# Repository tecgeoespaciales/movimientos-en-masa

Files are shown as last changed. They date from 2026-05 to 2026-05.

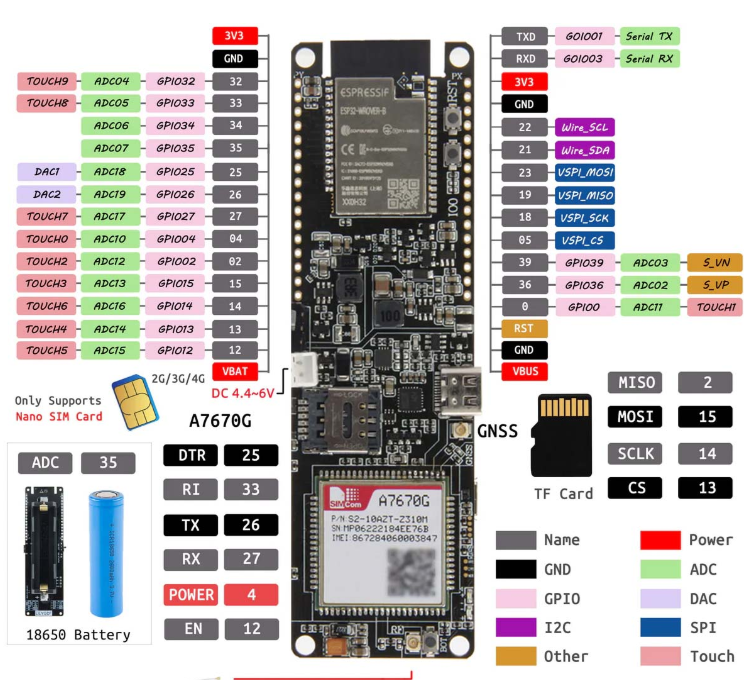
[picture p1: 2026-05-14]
docs-movimientos-en-masa/PINOUT-A7670G/PINOUT ESP32-A7670G.png

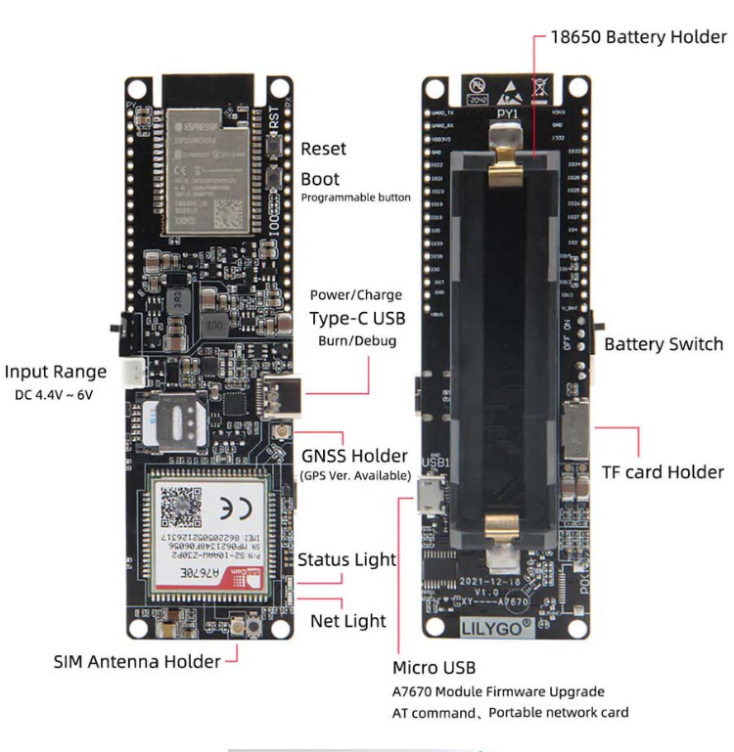
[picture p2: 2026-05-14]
docs-movimientos-en-masa/PINOUT-A7670G/ESP32-A7670G.png

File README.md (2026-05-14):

# Estación de monitoreo automática (EMA) - Movimientos en masa 🛰️⛰️

> Espacio de trabajo para la rama **profesional** del dispositivo **movimientos-en-masa**, desarrollado bajo los estándares técnicos del **Servicio Geológico Colombiano (SGC)**.

## 📂 Módulos del proyecto
Para una navegación detallada por los componentes del sistema, acceda a los siguientes módulos:

* 📑 **[docs-movimientos-en-masa](./Docs/)** – Manuales técnicos, de operación y seguridad.
* 🔌 **[hardware-movimientos-en-masa](./Hardware/)** – Esquemas electrónicos, PinOut y listado de componentes.
* 💻 **[firmware-movimientos-en-masa](./Firmware_ESP32/)** – Código fuente para ESP32 con protocolos de comunicación segura.
* ⚙️ **[mechanical-movimientos-en-masa](./Mechanical/)** – Archivos STL para impresión 3D en resina y ABS.
* 🎬 **[video-tutoriales-movimientos-en-masa](./Videos/)** – Guías visuales paso a paso para la operación y extracción de datos en campo.

---

## 📝 Descripción general
La **EMA (Estación de Monitoreo Automática)** es un sistema IoT de alta precisión diseñado para la detección temprana de deslizamientos. Utiliza un sensor óptico acoplado a un mecanismo de carrete y nylon para medir desplazamientos del terreno, transmitiendo datos en tiempo real mediante tecnología LTE.

## 🛠️ Especificaciones técnicas
* **Microcontrolador:** ESP32-WROVER-B (LilyGO T-A7670G).
* **Comunicación:** Módem SIMCom A7670G (Protocolo MQTT).
* **Sensor:** Encoder de herradura infrarrojo H206 (125 pulsos por metro).
* **Estampa:** RTC DS3231 para estampado de tiempo preciso.
* **Energía:** Panel solar 15W + batería Litio 18650.
* **Materiales:** Carrete y guías impresos en **resina ABS** de alta resistencia.

## 📐 Metodología de medición
La distancia de desplazamiento ($D$) se obtiene mediante el conteo de pulsos ($P$):
$$D = P \times 0.8000 \, \text{cm}$$

---

## 🔐 Seguridad y telemetría
El sistema garantiza la integridad de los datos para el SGC mediante:
1. **Capa de transporte:** Conexión cifrada **TLS (Puerto 1883)** hacia MQTT.

---

## 🚀 Guía de operación paso a paso

### 1. Preparación
* Instalar **Nano SIM** (Claro u operador de preferencia) y **MicroSD** (FAT32).
* Cargar batería 18650 (voltaje > 3.7V).

### 2. Calibración e instalación
* Fijar la caja hermética 15x15 en el sitio de monitoreo.
* Enrollar el nylon en el carrete y alinearlo con el sensor H206.
* Anclar el extremo del nylon al punto de referencia en el terreno.

### 3. Puesta en marcha
* Encender el interruptor. El sistema iniciará automáticamente el registro en red y la conexión MQTT.
* Verificar en el Dashboard (Node-RED) la recepción del primer paquete.

### 4. Descarga de datos (Modo local)
* En zonas sin cobertura, conectarse al Wi-Fi `EMA_SGC_CONFIG`.
* Acceder a `192.168.4.1` desde un navegador para descargar el archivo `LOGS.CSV`.

---

## ⚠️ Mantenimiento
* Limpiar el panel solar cada 3 meses, o antes de ser necesario.
* Revisar la tensión del nylon trenzado cada 3 meses , o antes de ser necesario.

---
**Autor:** Jhoiner Andretty Silva Montaño  
**Entidad:** Servicio Geológico Colombiano  
**Año:** 2026

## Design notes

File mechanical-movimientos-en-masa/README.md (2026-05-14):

# ⚙️ Especificaciones de fabricación mecánica (híbrido ABS - resina)

Este directorio contiene los archivos de diseño industrial para el ensamble del nodo de monitoreo **EMA - Movimientos en masa**. El sistema utiliza una combinación estratégica de materiales para garantizar precisión milimétrica y durabilidad estructural en campo.

## 📂 Inventario de piezas (.STL)

1.  **`CARRETE-CALIBRADOR.stl`**: Componente principal de medición. Su diámetro de 5.10 cm está optimizado para una resolución de 0.801 cm por pulso.
    * *Relación de campo:* 125 pulsos equivalen a 100 cm de desplazamiento lineal.
2.  **`ENCODER-8MM.stl`**: Acople de precisión diseñado para vincular el eje del encoder de 8mm con el sistema de rotación sin juegos mecánicos.
3.  **`CARRETE-NYLON.stl`**: Carrete de alta resistencia para el almacenamiento del hilo trenzado de 8 hilos.
4.  **`SOPORTE-H206.stl`**: Estructura de anclaje que garantiza el alineamiento perfecto entre el sensor óptico y el disco encoder.

## 🛠 Estándar de manufactura

Para asegurar el correcto funcionamiento del nodo bajo condiciones ambientales reales, se establecen los siguientes parámetros:

### 1. Componentes estructurales (ABS - FDM)
* **Material:** ABS (acrilonitrilo butadieno estireno).
* **Piezas:** Chasis, soportes y carrete de nylon.
* **Configuración:** Relleno al 60% (Giroide) y mínimo 4 capas de pared.
* **Propiedades:** Alta resistencia al impacto y estabilidad térmica hasta 60°C.

### 2. Componentes de Precisión (resina ABS - SLA/DLP)
* **Material:** Resina de ingeniería (Tough o ABS).
* **Piezas:** `CARRETE-CALIBRADOR` y `ENCODER-8MM`.
* **Propiedades:** Acabado superficial liso que minimiza la fricción y garantiza la fidelidad del conteo.

## 🔧 Notas de Ensamble y Mantenimiento

* **Alineación:** El sensor H206 debe estar centrado con las ranuras del disco para evitar errores de lectura por vibración o desajuste.
* **Fijación:** Se requiere tornillería M3 para el aseguramiento de los componentes al chasis.
* **Limpieza:** Mantener el disco encoder libre de polvo. Utilizar alcohol isopropílico únicamente para la limpieza del sensor óptico.

---
*Diseño y desarrollo técnico por: **Jhoiner Andretty Silva Montaño***

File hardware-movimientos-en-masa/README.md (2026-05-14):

# hardware-movimientos-en-masa
# 🔌 Hardware y electrónica - Nodo EMA

Este directorio contiene la especificación técnica de los componentes físicos y el esquema de conexiones desarrollado para el **Servicio Geológico Colombiano**. El diseño está optimizado para la detección de movimientos en masa mediante un sistema híbrido de alta precisión y bajo consumo.

## 📍 Análisis de componentes y conexiones (PinOut)

Cada terminal y periférico visualizado en el esquema de conexiones cumple una función vital para la autonomía y precisión del nodo:

### 1. Sensor óptico de herradura H206
* **Ubicación:** Conectado al **GPIO 32**.
* **Función:** Es el sensor principal de medición. Detecta la interrupción del haz infrarrojo al paso de las ranuras del disco encoder.
* **Detalle Técnico:** Configurado con una resistencia de **Pull-Up de 100kΩ** para estabilizar la señal y minimizar el consumo en *Deep Sleep*.

### 2. Unidad de procesamiento (LilyGO T-A7670G)
* **ESP32-WROVER-E:** Gestiona la lógica de control, el almacenamiento y la pila de protocolos.
* **Módem A7670G (Pines IO26/IO27):** Interfaz UART para el envío de telemetría GPRS/MQTT hacia el servidor central.
* **Control de Encendido (IO12/IO4):** Pines dedicados a la gestión de energía del módem, permitiendo apagarlo completamente cuando no hay transmisión.

### 3. Sincronización y tiempo (DS3231)
* **Interfaz:** Bus I2C (**SDA: IO21 / SCL: IO22**).
* **Función:** Garantiza que cada registro tenga un *timestamp* exacto, permitiendo la reconstrucción cronológica de los eventos geológicos.

### 4. Gestión energética solar
* **Panel solar:** 15W Modelo CL1615.
* **Lectura de Batería (IO35):** Entrada analógica (ADC) que permite al firmware monitorear el nivel de carga y reportarlo en la trama de datos para mantenimiento preventivo.

### 5. Almacenamiento redundante (MicroSD)
* **Interfaz:** Bus SPI (**CS: IO13**).
* **Función:** Respaldo físico de archivos CSV. Asegura que los datos no se pierdan si falla la cobertura celular.

## ⚙️ Especificaciones mecánicas integradas
Para asegurar la fidelidad del dato del sensor H206, el hardware se apoya en:
* **Eje:** Varilla lisa de acero de 8mm.
* **Soportes:** Rodamientos **KFL08** de alta eficiencia para un giro sin fricción.
* **Tracción:** Nylon trenzado de 8 hilos (elongación nula).

## 🛠️ Guía de ensamble y mantenimiento
1.  **Alineación crítica:** El disco encoder debe estar perfectamente centrado en la herradura del sensor H206 para evitar rozamientos.
2.  **Protección ambiental:** El hardware debe alojarse en la **Caja de paso 15x15 hermética** para proteger los circuitos de la humedad y el polvo.
3.  **Botón de servicio (IO0):** Se utiliza para activar el portal Wi-Fi local sin necesidad de abrir el equipo en campo.

---
**Autor:** Jhoiner Andretty Silva Montaño  
**Entidad:** Servicio Geológico Colombiano  
**Año:** 2026

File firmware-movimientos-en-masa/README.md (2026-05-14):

# 💾 Firmware EMA - Sistema de monitoreo de movimientos en masa

Este directorio contiene el desarrollo lógico integral para el microcontrolador **ESP32 (LilyGO T-A7670G)**. El firmware ha sido diseñado para garantizar la captura precisa de desplazamientos superficiales y su transmisión telemática bajo condiciones ambientales críticas.

## ❓ ¿Para qué sirve esta carpeta?
Esta carpeta es el **núcleo del sistema**. El firmware aquí alojado actúa como el "cerebro" del nodo EMA, encargándose de:
* **Interpretar el movimiento:** Traduce las señales físicas del sensor H206 en datos métricos de desplazamiento.
* **Gestión inteligente:** Controla cuándo el equipo debe "dormir" para ahorrar batería y cuándo debe "despertar" para reportar una alerta.
* **Puente de comunicación:** Transforma los datos recolectados en tramas MQTT para enviarlas vía satelital/celular al centro de datos del SGC.
* **Seguridad de datos:** Administra el respaldo local (MicroSD/LittleFS) para que nunca se pierda información por falta de señal.

## 🏗️ Arquitectura del software (FreeRTOS)
Para garantizar que no se pierda ningún pulso del encoder durante las tareas de comunicación, el firmware utiliza una arquitectura de doble núcleo:
* **Core 1 (Prioridad Crítica):** Ejecuta la tarea de vigilancia del sensor óptico H206. Detecta flancos de subida y bajada en el Pin 32 en tiempo real.
* **Core 0 (Gestión de Red):** Administra la pila TCP/IP, los comandos AT del módem A7670G y la sesión MQTT.

## ⚡ Gestión de energía y eficiencia
El sistema está optimizado para funcionar con un panel solar de 15W y una batería de respaldo:
* **Modo Deep Sleep:** El ESP32 entra en sueño profundo, reduciendo el consumo a microamperios.
* **Wake-up (EXT0):** El sistema despierta instantáneamente ante cualquier rotación del disco encoder.
* **Wake-up (Timer):** Reporte de estado de batería y señal cada hora.
* **Hardware:** Se implementa una resistencia de pull-up de 100kΩ para minimizar fugas de corriente en reposo.

## 🔐 Configuración de seguridad (Paso a Paso)
El firmware utiliza el archivo `config_env.h` para gestionar credenciales sensibles sin exponerlas en el historial de Git. Siga estas instrucciones para compilar:

1. En esta carpeta, cree un archivo nuevo llamado exactamente `config_env.h`.
2. Copie y pegue la siguiente estructura:

```cpp
#ifndef CONFIG_ENV_H
#define CONFIG_ENV_H

// --- CREDENCIALES GPRS (APN) ---
#define SECRET_APN        "internet.comcel.com.co" 
#define SECRET_GPRS_USER  ""
#define SECRET_GPRS_PASS  ""

// --- CONFIGURACIÓN BROKER MQTT ---
#define SECRET_MQTT_SERVER "00.000.000.0"   // IP Servidor a usar
#define SECRET_MQTT_PORT   1883
#define SECRET_MQTT_USER   "tu_usuario"
#define SECRET_MQTT_PASS   "tu_clave"
#define SECRET_MQTT_TOPIC  "movimientos_masa/final"

// --- ACCESO TÉCNICO LOCAL ---
#define SECRET_WIFI_AP_PASS "12345678" 

#endif

//-- AUTOR --
//**Autor:** Jhoiner Andretty Silva Montaño  
//**Entidad:** Servicio Geológico Colombiano  
//**Año:** 2026

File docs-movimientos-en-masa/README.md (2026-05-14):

# 📚 Documentación técnica y manuales - nodo EMA

Este directorio centraliza la base de conocimiento del sistema de monitoreo de movimientos en masa. Aquí se encuentran los manuales de operación, las guías de referencia y los registros de control desarrollados para asegurar la correcta implementación y mantenimiento del nodo en campo.

## 📄 Recursos disponibles en esta carpeta

### 1. Manual de operación principal
* **Archivo:** `Manual_operacion_EMA.docx` (Anteriormente *PlantillaManualdeoperacin_1.docx*)
* **Contenido:** Guía exhaustiva que cubre desde los objetivos del proyecto hasta los protocolos de instalación. Es el documento maestro para entender el funcionamiento del hardware y software.

### 2. Guía de calibración y resolución
De acuerdo con las pruebas de ingeniería documentadas, el sistema utiliza los siguientes parámetros para la conversión de datos mecánicos a digitales:
* **Resolución:** 0.801 cm por cada pulso del sensor H206.
* **Equivalencia:** 125 pulsos corresponden a 100 cm (1 metro) de desplazamiento.
* **Componente crítico:** Carrete calibrador de 5.10 cm de diámetro.

### 3. Control de versiones y cambios
* **Archivo:** `Control_de_Cambios.png` (Referencia visual)
* **Uso:** Registro histórico de las actualizaciones realizadas en el firmware, mejoras en el diseño de las piezas 3D y ajustes en los protocolos de comunicación MQTT.

## 🛠️ Referencias técnicas complementarias
Para profundizar en los submódulos del nodo, se recomienda consultar las siguientes referencias mencionadas en el manual:
* **Hardware:** LilyGO T-A7670 Series hardware manual.
* **Comandos AT:** SIMCom A7670 Series command manual (Envío de tramas CSV).
* **Sensor:** Datasheet genérico H206.

## 📊 Gestión y visualización
La documentación describe el flujo de datos hacia la interfaz de **Node-RED**, detallando la configuración de los dashboards para la visualización de desplazamientos y niveles de batería reportados por el nodo.

---
**Autor:** Jhoiner Andretty Silva Montaño  
**Entidad:** Servicio Geológico Colombiano  
**Año:** 2026

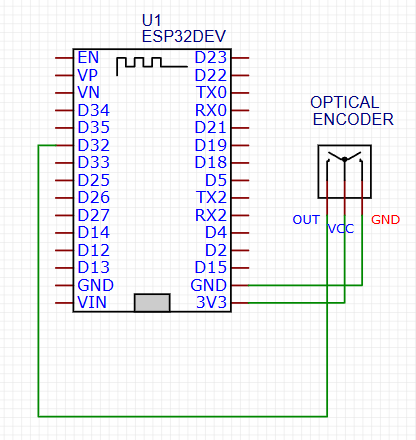
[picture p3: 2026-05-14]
docs-movimientos-en-masa/ESQUEMATICOS-MOV-MASA/CIRCUITO_ESP32-SENSOR_H206.png

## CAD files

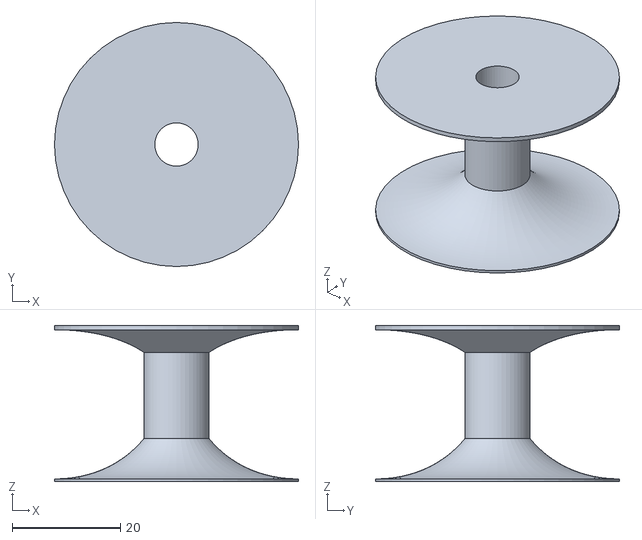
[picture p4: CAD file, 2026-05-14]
mechanical-movimientos-en-masa/PIEZAS-PROTOTIPO-01/CARRETEDIVIDIDO#2.stl
45.0 x 45.0 x 28.8

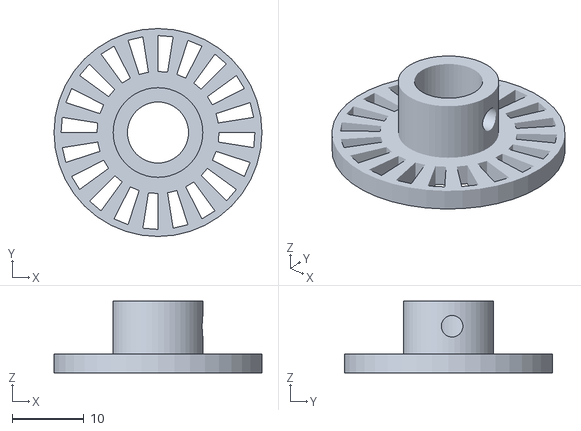
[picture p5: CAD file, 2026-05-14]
mechanical-movimientos-en-masa/PIEZAS-PROTOTIPO-FINAL/ENCODER-8MM.stl
29.0 x 29.0 x 10.0

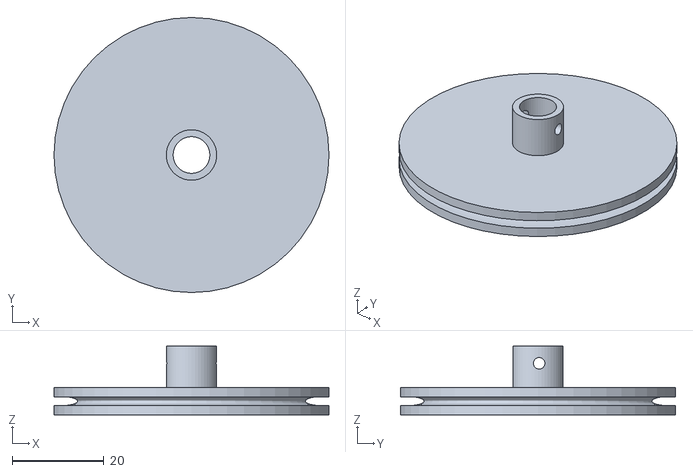
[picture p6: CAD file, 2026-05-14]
mechanical-movimientos-en-masa/PIEZAS-PROTOTIPO-01/POLEAINICIAL.stl
60.0 x 60.0 x 15.0

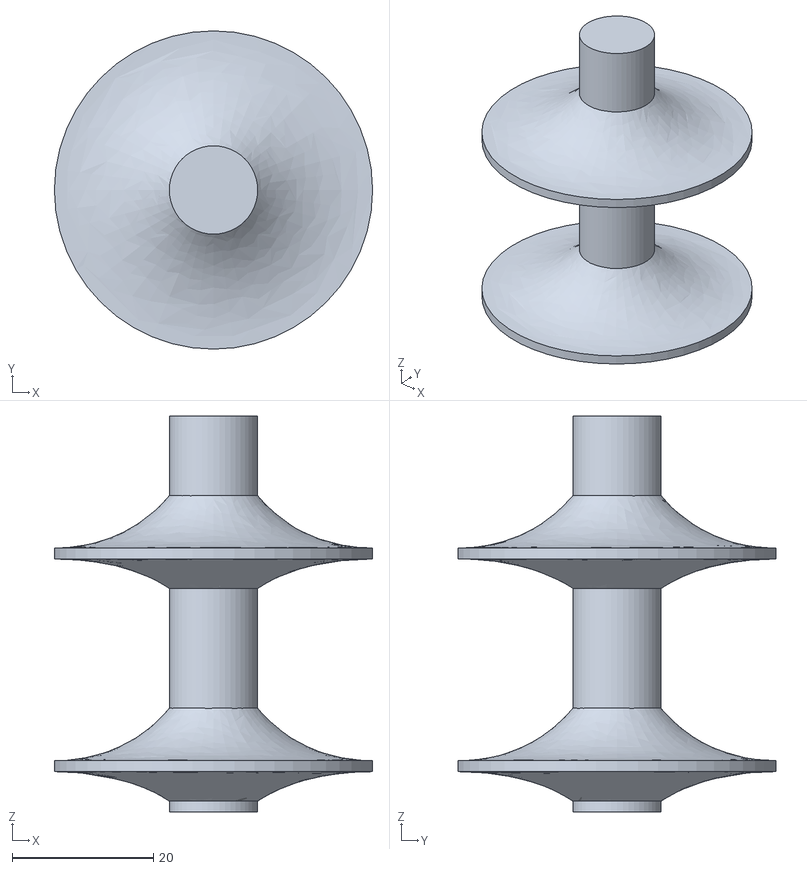
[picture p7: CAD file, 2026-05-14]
mechanical-movimientos-en-masa/PIEZAS-PROTOTIPO-FINAL/CARRETE-NYLON.stl
45.0 x 45.0 x 56.0

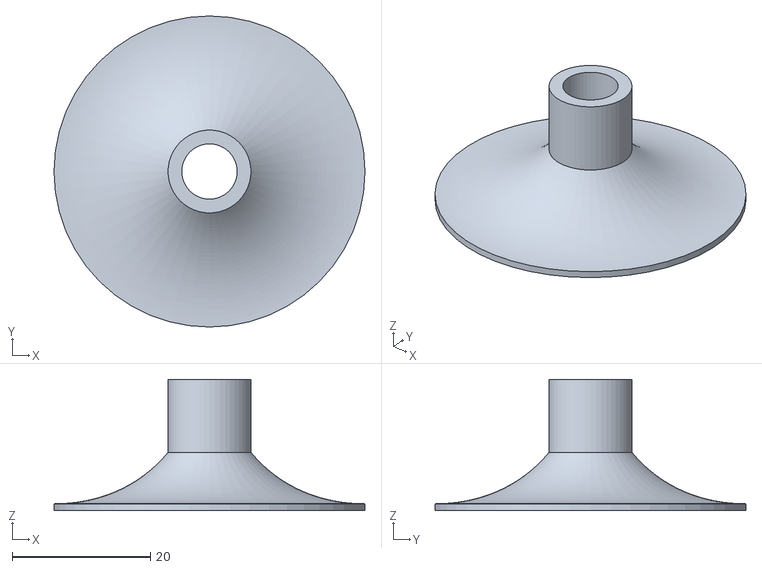
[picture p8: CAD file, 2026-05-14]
mechanical-movimientos-en-masa/PIEZAS-PROTOTIPO-01/CARRETEDIVIDIDO#3.stl
45.0 x 45.0 x 19.0

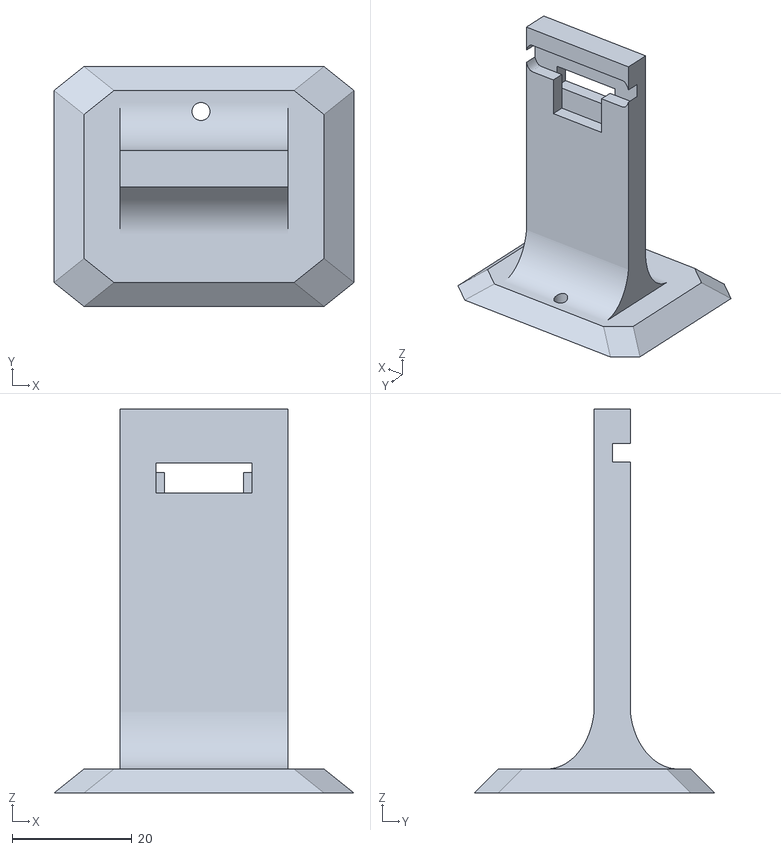
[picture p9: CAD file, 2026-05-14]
mechanical-movimientos-en-masa/PIEZAS-PROTOTIPO-FINAL/SOPORTE-H206.stl
50.0 x 40.0 x 64.0

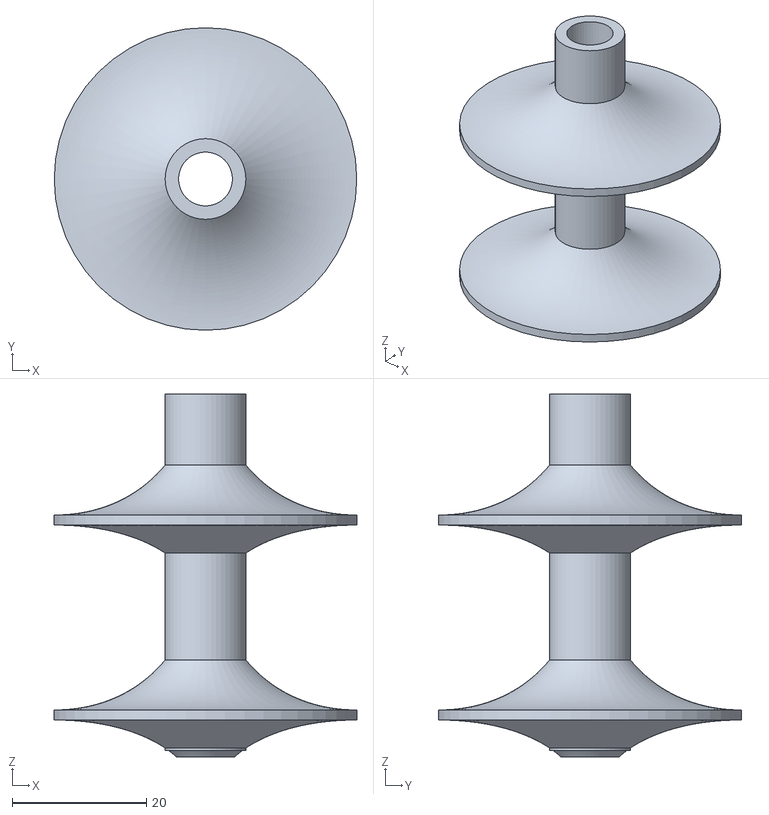
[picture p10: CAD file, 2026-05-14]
mechanical-movimientos-en-masa/PIEZAS-PROTOTIPO-01/CARRETE.stl
45.0 x 45.0 x 54.0

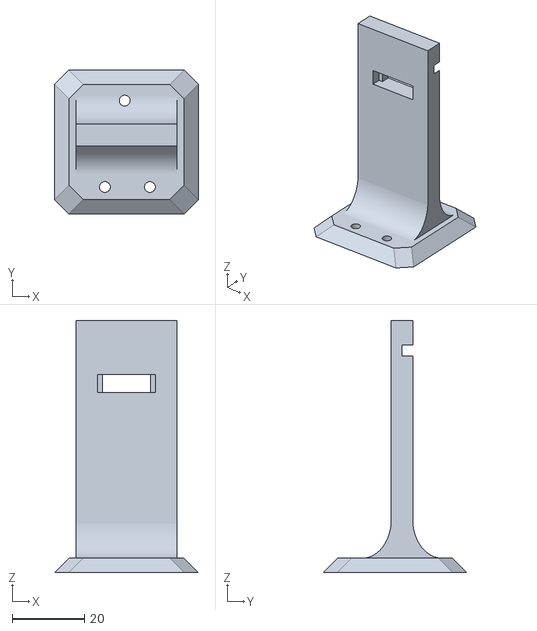
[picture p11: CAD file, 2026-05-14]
mechanical-movimientos-en-masa/PIEZAS-PROTOTIPO-01/BASESENSOROPTICOINICIAL.stl
40.0 x 40.0 x 70.0

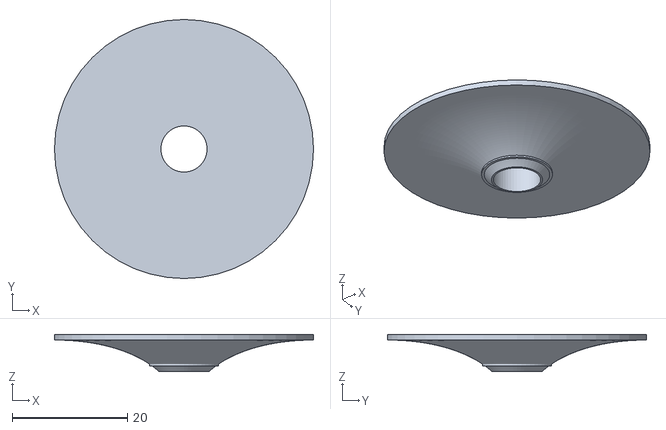
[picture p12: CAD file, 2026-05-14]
mechanical-movimientos-en-masa/PIEZAS-PROTOTIPO-01/CARRETEDIVIDIDO#1.stl
45.0 x 45.0 x 6.50

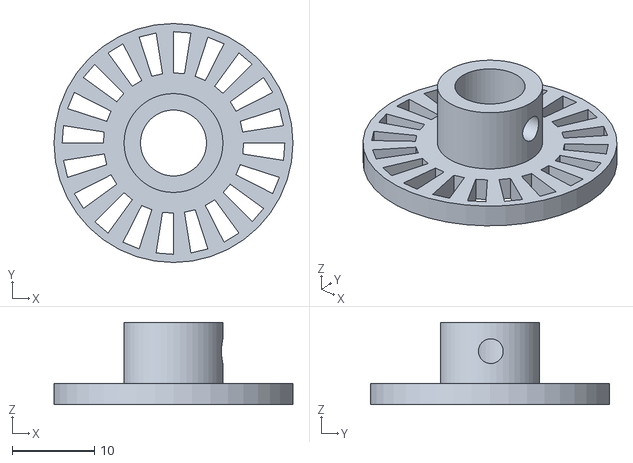
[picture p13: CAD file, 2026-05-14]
mechanical-movimientos-en-masa/PIEZAS-PROTOTIPO-01/ENCODERINICIAL.stl
29.0 x 29.0 x 10.0

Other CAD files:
mechanical-movimientos-en-masa/PIEZAS-PROTOTIPO-FINAL/CARRETE-CALIBRADOR.stl

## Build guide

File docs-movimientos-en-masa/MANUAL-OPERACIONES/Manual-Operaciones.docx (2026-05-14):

MANUAL TECNICO EMA - MOVIMIENTOS EN MASA

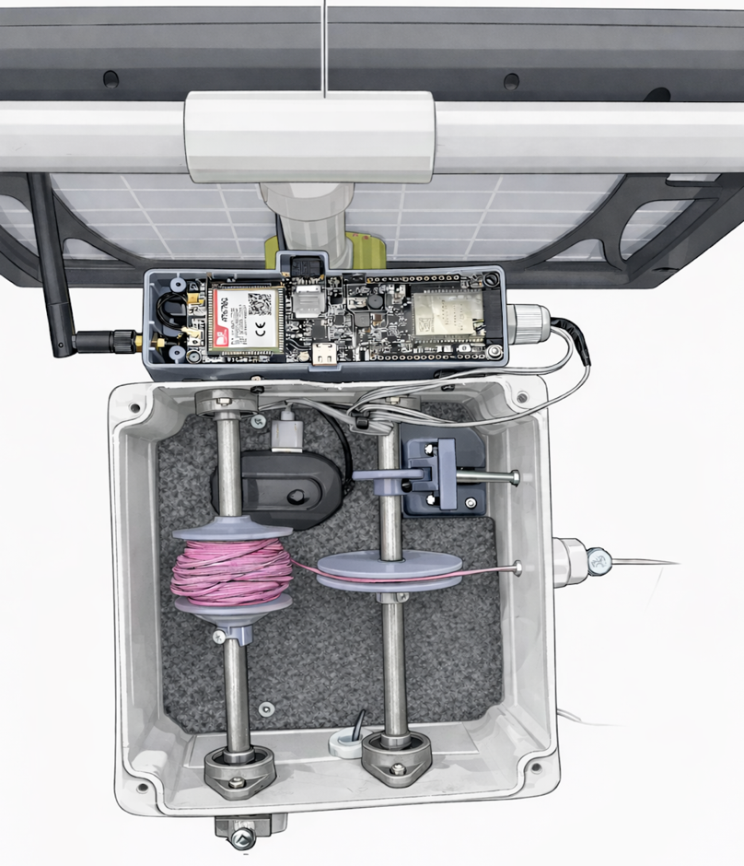
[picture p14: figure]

SERVICIO GEOLÓGICO COLOMBIANO

Bogotá, 2026

TABLA DE CONTENIDO

# 1. OBJETIVO

Establecer los lineamientos técnicos y operativos para el uso correcto del sistema de monitoreo de movimientos de masa basado en tecnología ESP32 y telemetría A7670G, con el fin de asegurar la recolección precisa de datos geológicos con marcas de tiempo exactas y garantizar la integridad física de los nodos durante su operación en terreno.

# 2. ALCANCE

Este manual de operación aplica para todos los procesos de instalación, configuración de hardware, sincronización de tiempo mediante RTC, monitoreo autónomo de desplazamientos y gestión de respaldos de datos realizados por el personal técnico en los sitios de monitoreo.

# 3. TÉRMINOS Y DEFINICIONES

A7670G: Módulo de comunicación celular de grado industrial que soporta bandas 4G LTE y GPRS. Es el encargado de establecer la conexión con la red móvil para la transmisión inalámbrica de la telemetría hacia el servidor central.

APN (Access Point Name): Nombre del punto de acceso que actúa como pasarela entre la red celular del operador (ej. Claro) y la red de internet pública. Es una configuración crítica para que el módem pueda navegar.

Baudios (Baud rate): Unidad de medida que representa la velocidad de transmisión de datos en una comunicación serial. Para este sistema, la comunicación entre el ESP32 y el módem se sincroniza habitualmente a 115200 baudios.

CSV (Comma-Separated Values): Formato de archivo de texto plano diseñado para el almacenamiento de datos tabulares, donde cada registro (distancia, batería, tiempo) se separa mediante una coma para facilitar su lectura en hojas de cálculo o bases de datos.

Deep Sleep: Estado de ultra bajo consumo de energía en el cual el microcontrolador desactiva sus núcleos de procesamiento y la mayoría de sus periféricos. El equipo solo consume microamperios y "despierta" únicamente por interrupciones externas, como el movimiento del sensor.

EMA: Estación de monitoreo automática.

REMA: Red de estaciones de monitoreo automáticas.

Encoder Rotativo Óptico (H206): Sensor de barrera infrarroja compuesto por un emisor y un receptor. Detecta el movimiento mecánico del terreno mediante los pulsos generados por el paso de las ranuras de un disco encoder, convirtiendo el desplazamiento físico en datos digitales.

ESP32: Microcontrolador de doble núcleo de alto rendimiento con capacidades integradas de Wi-Fi y Bluetooth, que actúa como la unidad central de procesamiento (CPU) y controladora de todos los sensores del nodo.

GPRS (General Packet Radio Service): Tecnología de transmisión de datos por paquetes sobre redes celulares. Se utiliza como protocolo de respaldo para asegurar el envío de la información en zonas donde la cobertura 4G es deficiente.

GPIO (General Purpose Input/Output): Pines de propósito general presentes en la placa del microcontrolador, los cuales pueden ser configurados por software como entradas para recibir señales de sensores o salidas para controlar actuadores.

I2C (Inter-Integrated Circuit): Protocolo de comunicación serial por bus que utiliza solo dos cables para conectar múltiples circuitos integrados. En este proyecto, se utiliza para la comunicación entre el ESP32 y el módulo de reloj RTC DS3231.

MQTT (Message Queuing Telemetry Transport): Protocolo de mensajería basado en publicación y suscripción, diseñado específicamente para dispositivos con recursos limitados (IoT) y redes de baja calidad, permitiendo el envío eficiente de datos hacia el servidor Node-RED.

Node-RED: Entorno de programación visual basado en flujo que permite la recepción de mensajes MQTT para su procesamiento, almacenamiento y visualización gráfica mediante dashboards interactivos.

RTC (DS3231): Módulo de Reloj de Tiempo Real de alta precisión que incorpora un oscilador compensado por temperatura. Su función es proporcionar la fecha y hora exacta (estampado de tiempo) a cada registro, incluso si el equipo principal pierde la alimentación.

Trama de Datos: Estructura lógica de información que empaqueta diferentes variables (ID del nodo, marca de tiempo, distancia acumulada y nivel de batería) en un solo mensaje para su envío.

# 4. DESARROLLO

El sistema de monitoreo opera bajo el principio de detección de eventos mecánicos por interrupción de haz infrarrojo. El nodo se mantiene en estado de ultra bajo consumo (Deep Sleep) para prolongar la autonomía de la batería, despertando únicamente cuando el sensor óptico detecta un movimiento físico en el terreno (desplazamiento de masa). Una vez activo, el sistema procesa la señal, le asigna una marca de tiempo precisa mediante el RTC DS3231 y transmite la información vía telemetría celular 4G:

## 4.1 Especificaciones del Equipo

### Microcontrolador:

ESP32-WROVER-B integrado en placa LilyGO T-A7670G.


Ilustración 1: Diagrama ESP32-A7670G, Fuente: https://www.puntoflotante.net/NODEMCU-ESP32-BLUETOOTH-WIFI-DUAL-CORE.htm (https://github.com/Xinyuan-LilyGO/LilyGo-Modem-Series)

### Módulo de Comunicación:

SIMCom A7670G (LTE Cat-1) con soporte para bandas nacionales.

Ilustración 2: ANTENA-A7670G, Fuente: https://www.puntoflotante.net/NODEMCU-ESP32-BLUETOOTH-WIFI-DUAL-CORE.htm (https://github.com/Xinyuan-LilyGO/LilyGo-Modem-Series)

### Sensor de Medición:

Encoder óptico de herradura (ranura) FC-03.

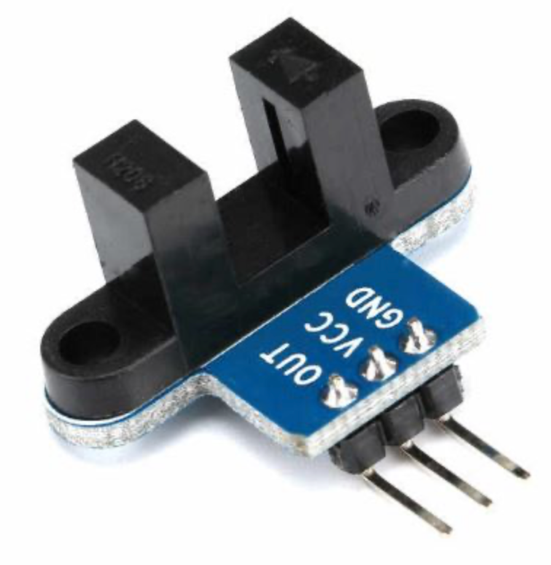
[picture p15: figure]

Ilustración 3: Sensor Enconder H206, Fuente: https://www.alldatasheet.es/view_datasheet.jsp?Searchword=H206&sField=2 (https://www.mactronica.com.co/sensor-contador-encoder-optico)

### Sincronización de Tiempo:

Módulo RTC DS3231 de alta precisión (I2C).

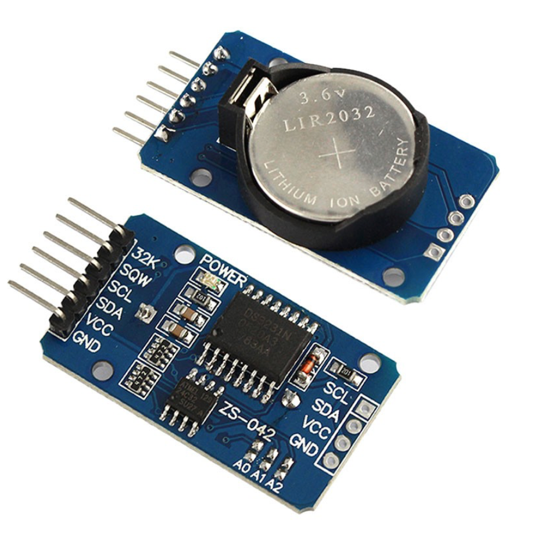
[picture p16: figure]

Ilustración 4: RTC DS3231. Fuente: https://www.alldatasheet.com/html-pdf/112132/DALLAS/DS3231/215/1/DS3231.html

### Panel Solar Portátil 15w Para Baterías CL1615:

panel fotovoltaico de 15W conectado al puerto USB, el cual suministra una tensión regulada de 5V. Esta configuración garantiza la autonomía del nodo al alimentar simultáneamente el circuito y gestionar la recarga de la batería interna, cubriendo con solvencia los picos de consumo del módem A7670G durante la transmisión de datos.

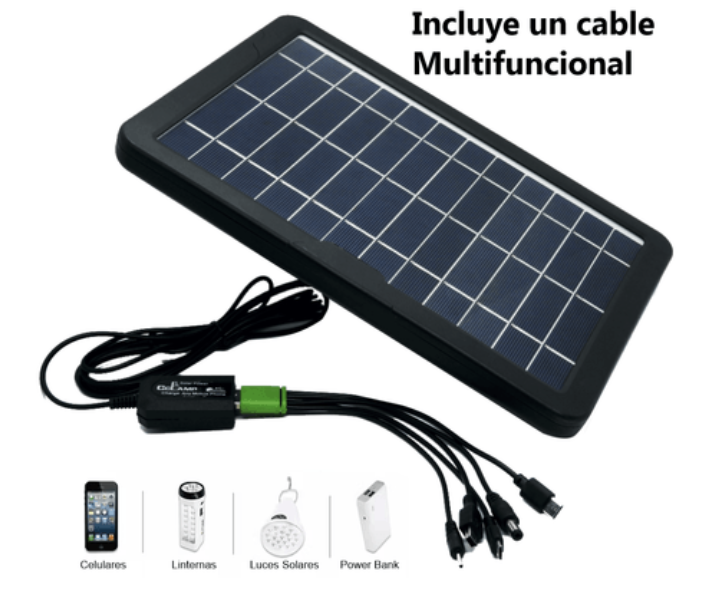
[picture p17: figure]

Ilustración 5: Panel solar de 15w. Fuente: https://www.olimpica.com/panel-solar-portatil-15w-para-baterias-y-dispositivos-12v-1002378697/p

### Caja de paso 15X15 hermética:

Caja plástica de paso ampliamente utilizada para proyectos eléctricos, electrónicos, instalación de cámaras de seguridad, impulsores, entre otras aplicaciones.

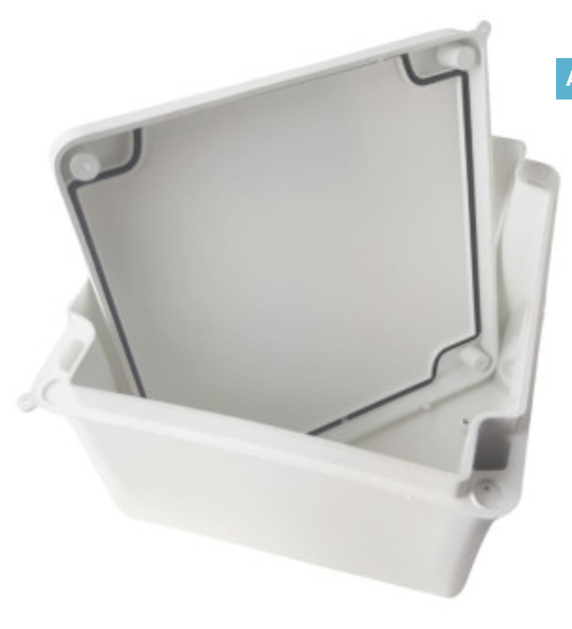
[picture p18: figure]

Ilustración 5: Caja de paso 15x15 hermética, Fuente: https://ssdielect.com/cajas-para-proyectos/4625-caja-de-paso-15x15.html

### Varilla lisa en acero de 8mm:

Varilla lisa de acero ideal para guías lineales de 8mm y aplicaciones estructurales.

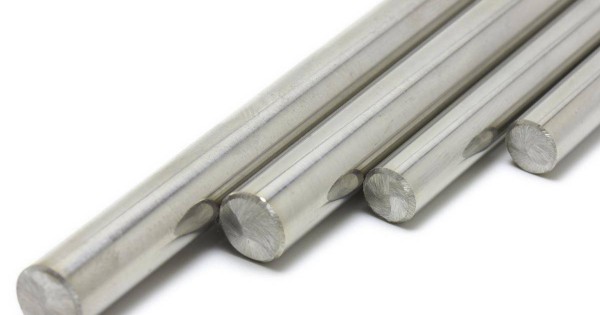
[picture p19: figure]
▷Varilla lisa calibrada diámetro 8mm - Cortada a medida - HTA3D ✓

Ilustración 6: Varilla lisa de 8 mm, Fuente: https://bigtronica.com/cnc-3d-partes/guias-lineales/varilla-lisa-acero-8mm-50cm-5053212007416.html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

### Tornillo y tuercas M3:

Los tornillos permiten que las piezas que están sujetas puedan ser desmontadas cuando la ocasión lo requiera.

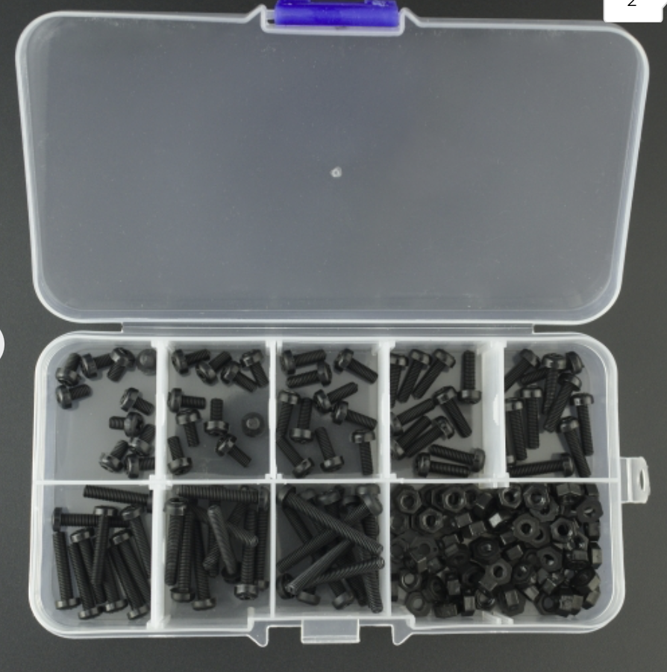
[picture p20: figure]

Ilustración 7: Caja de tornillos y tuercas M3, Fuente: https://ssdielect.com/cajas-para-proyectos/4625-caja-de-paso-15x15.html (https://www.vistronica.com/herramientas/tornilleria-/kit-de-160-tornillos-y-tuercas-nylon-m3-surtidos-negros-detail.html)

### Rodamiento KFL08:

Esta chumacera permite sujetar una varilla roscada de 8MM, permite que gire libremente y firme sobre una superficie vertical.

Ilustración 8: Rodamiento KFL08, Fuente: https://www.mactronica.com.co/rodamiento-kfl08-8mm-para-impresora-3d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

### Nylon de 8 hilos trenzado:

Hilo trenzado impermeable de alta resistencia.

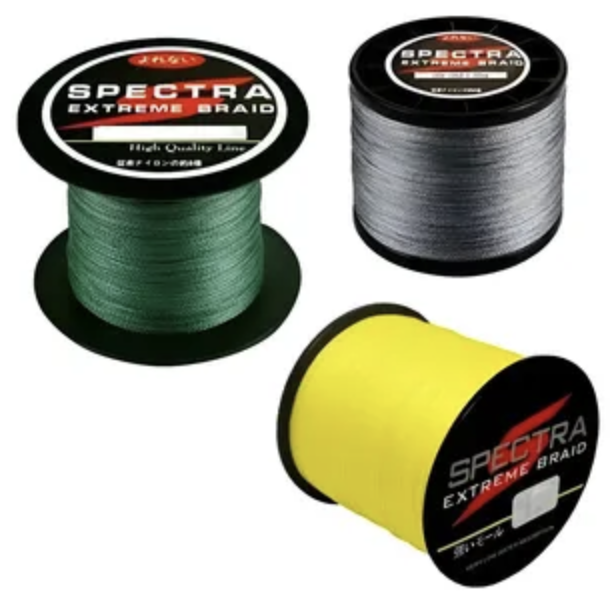
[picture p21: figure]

Ilustración 9: Nylon trenzado de 8 líneas, Fuente: https://www.google.com/url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 (https://www.google.com/url?rct=j&opi=89978449)

### Carrete de Nylon en 3D en Resina ABS:

Carrete diseñado en 3D por su alta resistencia al impacto y estabilidad térmica en el campo.

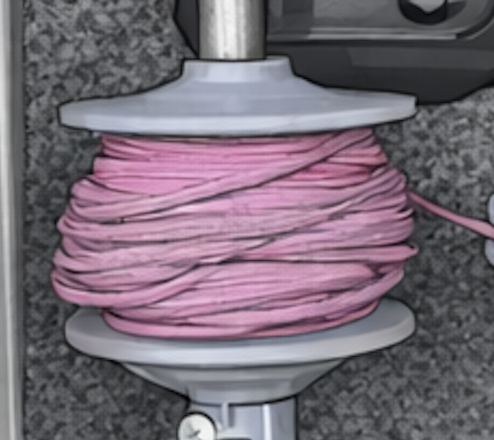
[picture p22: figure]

Ilustración 10: Carrete Nylon 3D movimientos en masa. Fuente: Propia SGC.

### Guía de calibración en 3D en Resina ABS:

Guía diseñada en 3D por su alta resistencia al impacto y estabilidad térmica en el campo, esta nos permite mantener una medida estándar de acuerdo a su tamaño para el entorno de calibración del dispositivo con un diámetro de 5mm.

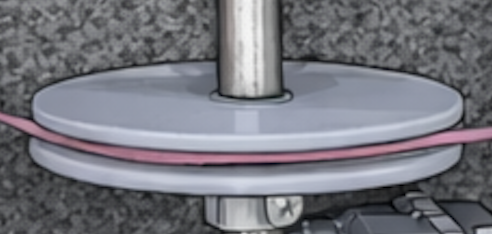
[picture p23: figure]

Ilustración 11: Guía de calibración 3D movimientos en masa. Fuente: Propia SGC.

### Base de sensor H206 en 3D en Resina ABS:

Guía diseñada en 3D por su alta resistencia al impacto y estabilidad térmica en el campo, esta nos permite mantener una medida promedio para centrar el sensor con la rueda de encoder para precisión de lectura

Ilustración 12: Base de sensor H206 3D movimientos en masa. Fuente: Propia SGC.

### Impresión 3D en material ABS:

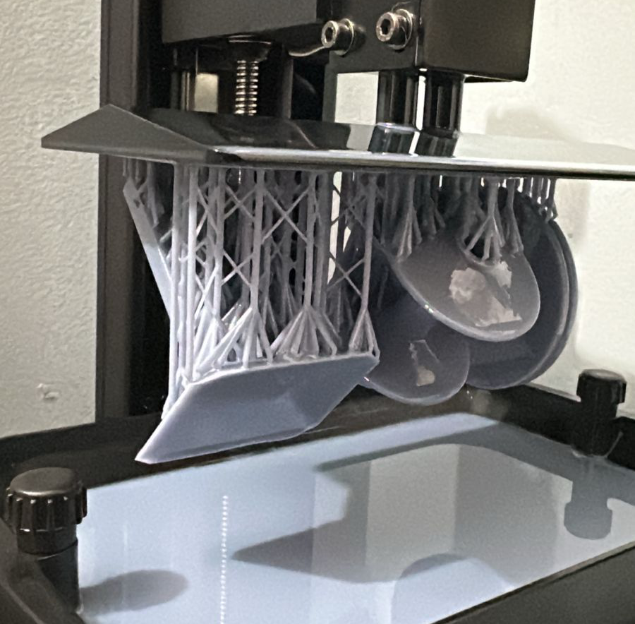
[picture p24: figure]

Ilustración 13: Impresiones 3D movimientos en masa. Fuente: Propia SGC.

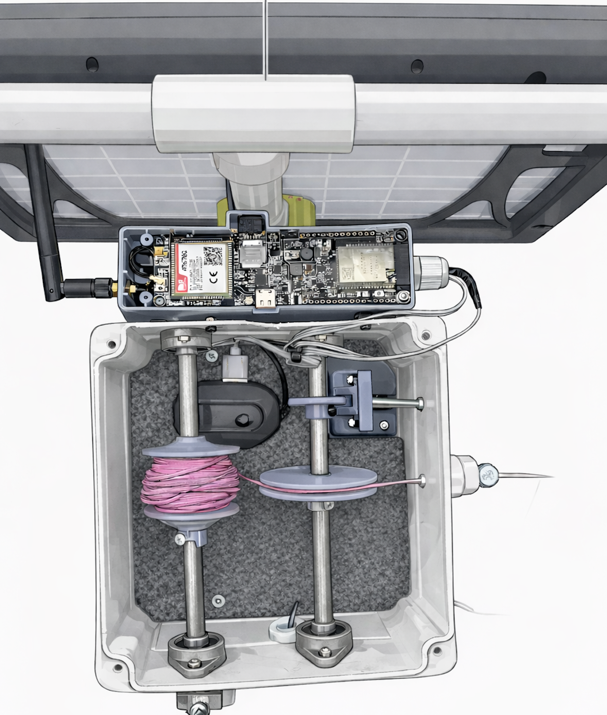
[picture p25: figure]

Ilustración 14: Prototipo movimientos en masa. Fuente: Propia SGC.

### Almacenamiento:

Ranura MicroSD para respaldo local de datos en formato CSV.


Ilustración 15: Diagrama de Pines ESP32-A7670G, Fuente: https://www.puntoflotante.net/NODEMCU-ESP32-BLUETOOTH-WIFI-DUAL-CORE.htm (https://github.com/Xinyuan-LilyGO/LilyGo-Modem-Series)

## 4.2 Condiciones Ambientales y Requisitos Eléctricos

### Alimentación:

Batería de Litio 18650 (3.7V - 4.2V). Soporta carga mediante panel solar de 5VDC.

Ilustración 16: Batería de litio INR 18650, Fuente: https://datasheet4u.com/datasheets/TENERGY/18650/1408721

### Rango de Temperatura:

Operación óptima entre -10°C y 60°C.

### Protección:

El chasis de ABS ofrece protección estructural, pero requiere un contenedor externo (caja de paso) para garantizar estanqueidad IP contra lluvia y humedad extrema.

## 4.3 Recomendaciones y Precauciones de Seguridad

### Seguridad Eléctrica:

Debido al bajo voltaje de operación (DC), el equipo no representa riesgo de electrocución. No obstante, evite cortocircuitos en los terminales de la batería que puedan generar calor excesivo o daños al material ABS.

### Manipulación:

No realizar modificaciones a la placa microcontroladora esp32-A7670g

### Uso del ABS:

Evite exponer las piezas de ABS a solventes fuertes como la acetona, ya que degradan el material instantáneamente.

## 4.4 Equipo de Cómputo y Software

### Servidor de Datos:

Broker MQTT (Mosquitto) y flujo en Node-RED para visualización en Dashboard.

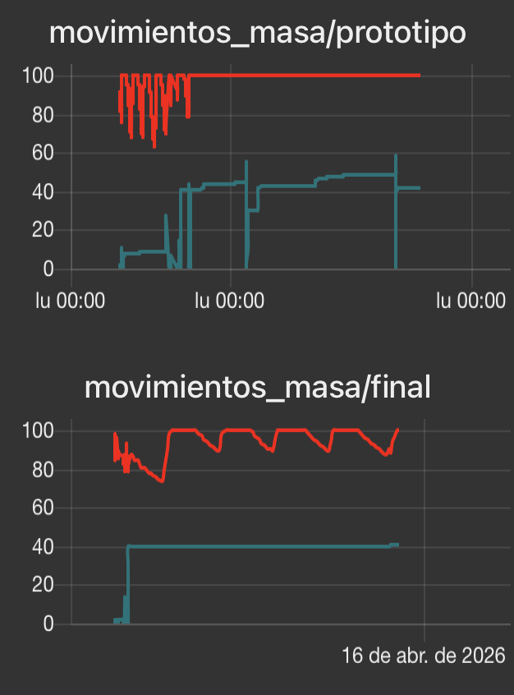
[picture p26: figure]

Ilustración 17: Node-RED (Dashboard) movimientos en masa. Fuente: Propia SGC.

### Software de Configuración:

Navegador web para acceso al portal cautivo (IP 192.168.4.1) en modo de descarga manual.

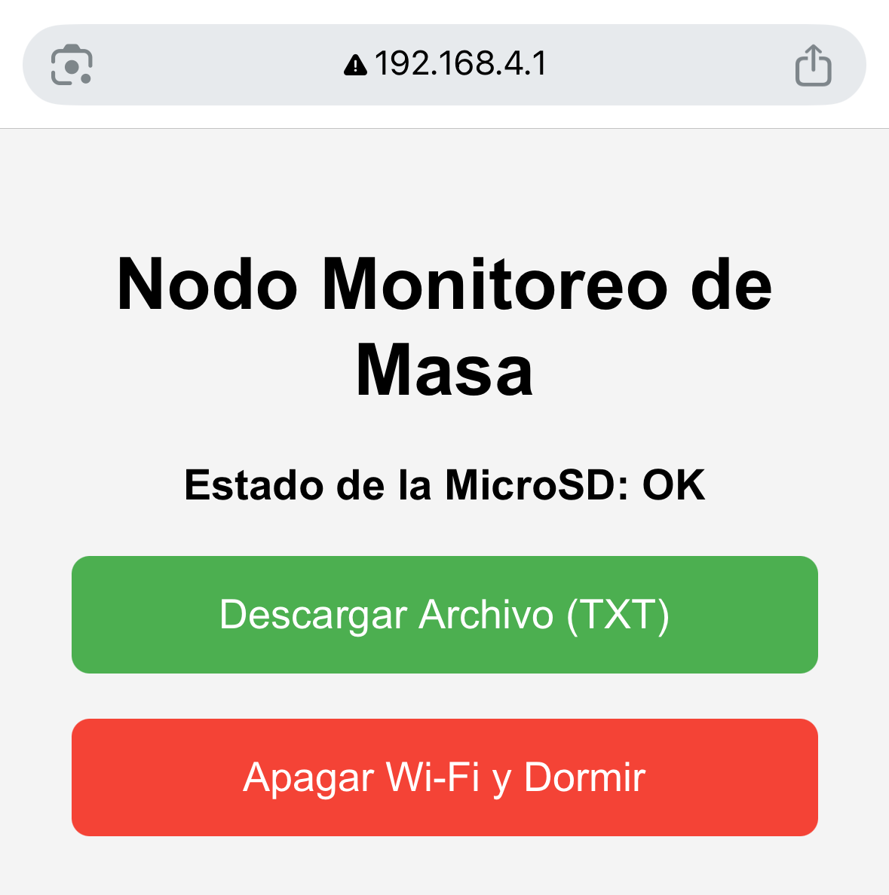
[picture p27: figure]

Ilustración 18: Extracción de datos movimientos en masa. Fuente: Propia SGC.

## 4.5 Identificación

Cada EMA cuenta con un nodo que debe ser identificado externamente con el código del proyecto (movimientos_masa) y el tópico del nodo asignado en el código fuente para facilitar su rastreo en la plataforma de telemetría (mqtt_topic = "movimientos_masa/xxxxx"), "xxxx" corresponde al nombre del dispositivo.

## 4.6 Mantenimiento de Rutina y Verificación

### Limpieza:

Utilizar exclusivamente alcohol isopropílico para limpiar el sensor H206 y el disco encoder. El polvo en la ranura es la causa principal de fallos en la detección.

### Inspección de materiales mecánicos:

Verificar visualmente que no existan fracturas en los soportes debido a la exposición en exteriores prolongados y fatiga mecánica de los componentes.

### RTC:

Comprobar semestralmente que la batería de respaldo (CR1220) mantenga el voltaje (3V) para evitar la pérdida de sincronización de hora.

### Almacenamiento de datos manual:

En caso de requerir una copia de seguridad física sin retirar la tarjeta del nodo, se debe activar el Modo de Extracción mediante el Pin 0. Este procedimiento habilita un punto de acceso Wi-Fi local que permite descargar el archivo backup_masa.txt directamente a un dispositivo móvil. Se recomienda realizar esta descarga tras eventos críticos para asegurar la redundancia de la información.

### Cambio de memorias MicroSD:

Para asegurar la integridad del sistema de archivos, el cambio de la tarjeta debe realizarse únicamente con el equipo desenergizado (Switch en OFF). Debido a que los registros en formato CSV generan archivos de poco peso, una memoria de 1GB es suficiente para la operación del nodo. Como medida de mantenimiento preventivo, se recomienda sustituir la tarjeta MicroSD cada año, evitando así posibles errores de lectura/escritura por desgaste físico o exposición a condiciones climáticas.

### Comprobación de voltajes de baterías:

Utilizando un multímetro digital en la escala de Corriente Continua (VDC), se debe medir el voltaje en los terminales del conector JST de la placa LilyGO:

- Voltaje Nominal: 3.7V.
- Voltaje de Carga Máxima: 4.2V (procedente del panel solar).
- Voltaje Crítico: Si la medición es inferior a 3.3V, el sistema puede presentar inestabilidad en la transmisión GPRS; en este caso, se requiere una carga solar completa antes de retomar el monitoreo activo.

## 4.7 Diagrama de configuración y funcionamiento.

El funcionamiento del sistema de monitoreo se divide en las siguientes fases operativas, las cuales deben ejecutarse secuencialmente para garantizar la integridad de las mediciones:

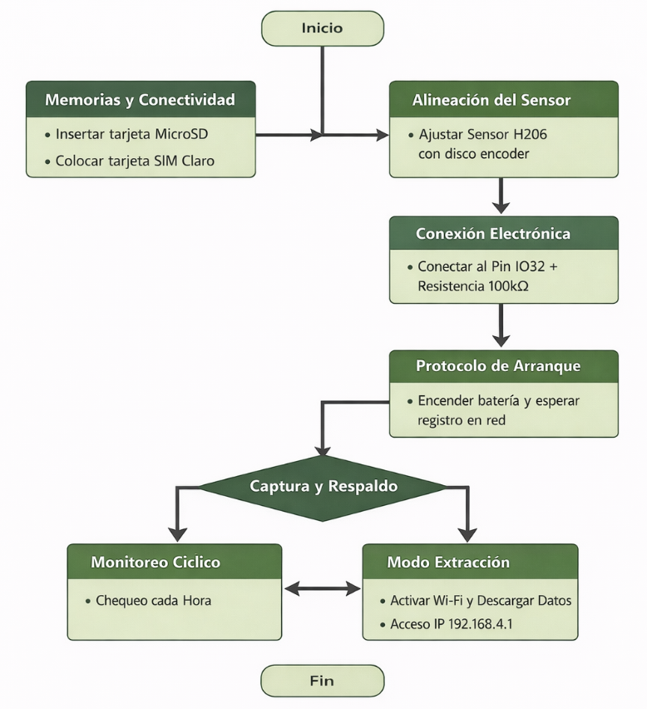
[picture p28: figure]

Ilustración 19: Diagrama de flujo movimientos en masa. Fuente: Propia SGC.

### Memorias y Conectividad:

Inserte la tarjeta MicroSD en la ranura lateral de la ESP32-A7670G para el respaldo local y la tarjeta SIM (operador Claro) en la ranura superior para la conexión GPRS.

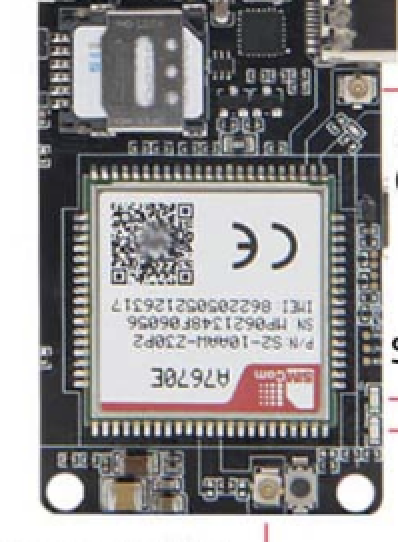
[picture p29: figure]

Ilustración 20: conexión nano sim. Fuente: Propia SGC.

Ilustración 21: conexión micro sd. Fuente: Propia SGC.

### Alineación del Sensor:

Asegúrese de que el sensor óptico de herradura (referencia H206) esté perfectamente alineado con las ranuras del disco encoder para evitar lecturas erróneas.

Ilustración 22: Encoder óptico en base de ABS en resina. Fuente: Propia SGC.

### Conexión Electrónica Sensor H206:

Verifique que la conexión al Pin IO32 y VCC (3.3v) del ESP32 incluya la resistencia de pull-up de 100kΩ. Esta configuración es crítica, ya que ha sido usada para reducir la corriente de consumo al mínimo nivel posible, prolongando la autonomía del nodo durante los periodos de monitoreo en campo.

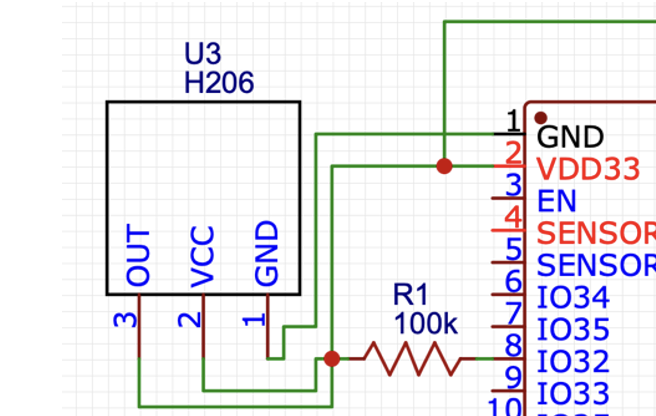
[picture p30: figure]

Ilustración 23: Circuito Electrónico encoder óptico. Fuente: Propia SGC.

### Protocolo de Arranque:

Al conectar la batería de alimentación debemos encender el switch de alimentación para que el panel pueda recargar la batería durante el día y no se descargue el sistema, el microcontrolador activa la llave maestra de energía a través del Pin 12. Se debe esperar un lapso de 10 a 15 segundos para que el módem celular complete su registro en la red y sincronice la hora del sistema.

### Captura en Tiempo Real:

El sistema permanece habitualmente en estado de bajo consumo (Deep Sleep) y se activa de forma instantánea al detectar el primer movimiento del terreno. Gracias al uso del segundo núcleo del ESP32, el dispositivo es capaz de recolectar los pulsos del encoder de manera dedicada y sin interrupciones. Si el deslizamiento es constante, el sistema mantiene la captura activa por un periodo de 30 segundos; no obstante, si el evento de masa se detiene antes, el equipo finaliza la trama de inmediato para asegurar que el dato reportado sea exacto y no se pierda información durante el desplazamiento.

### Registro en Almacenamiento Local y Transmisión de Mensajería

Una vez que el segundo núcleo del ESP32 finaliza la ventana de captura de 30 segundos, el firmware ejecuta un proceso de respaldo dual para evitar cualquier pérdida de información:

### Respaldo Local Inmediato:

Antes de intentar la conexión inalámbrica, el sistema genera una trama de texto plana (CSV) y la escribe en el archivo backup_masa.txt dentro de la tarjeta MicroSD. Este paso es prioritario y garantiza que, aunque falle la red celular, el dato físico ya esté asegurado en el hardware.

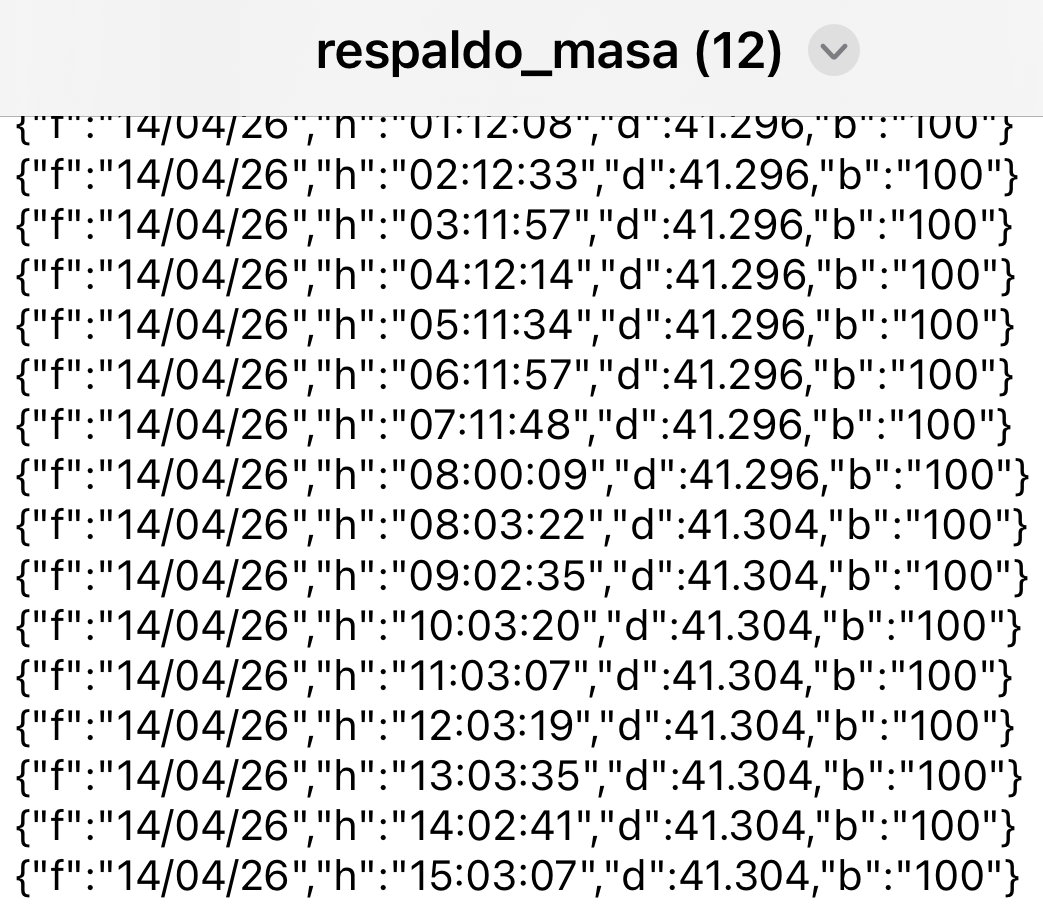
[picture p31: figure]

Ilustración 24: Respaldo y trama de datos movimientos en masa. Fuente: Propia SGC.

### Transmisión GPRS (MQTT):

Simultáneamente, el módem procesa la misma cadena de texto y la publica en el servidor central mediante el protocolo MQTT. Esta redundancia asegura que el historial del servidor y el de la memoria física sean idénticos, manteniendo la base de datos actualizada en tiempo real.

## 5. Monitoreo de Vigilancia Cíclica

Tras reportar un evento de movimiento brusco, el nodo retoma automáticamente su ciclo de vigilancia programada cada hora. Este chequeo periódico tiene como objetivo verificar variaciones lentas o acumuladas en la posición del encoder (H206) que no alcanzaron a disparar la alerta de movimiento constante. Esto garantiza un seguimiento continuo de la estabilidad del terreno, incluso en periodos de aparente calma.

## 6. Procedimiento de Descarga Manual (Modo Extracción)

En escenarios donde la conectividad a internet sea inexistente, el usuario puede recuperar los datos físicamente sin retirar la tarjeta MicroSD:

Activación: Presione el Pin 0 para habilitar el servidor Wi-Fi interno del nodo el cual se ubica en la parte frontal de la caja de control.

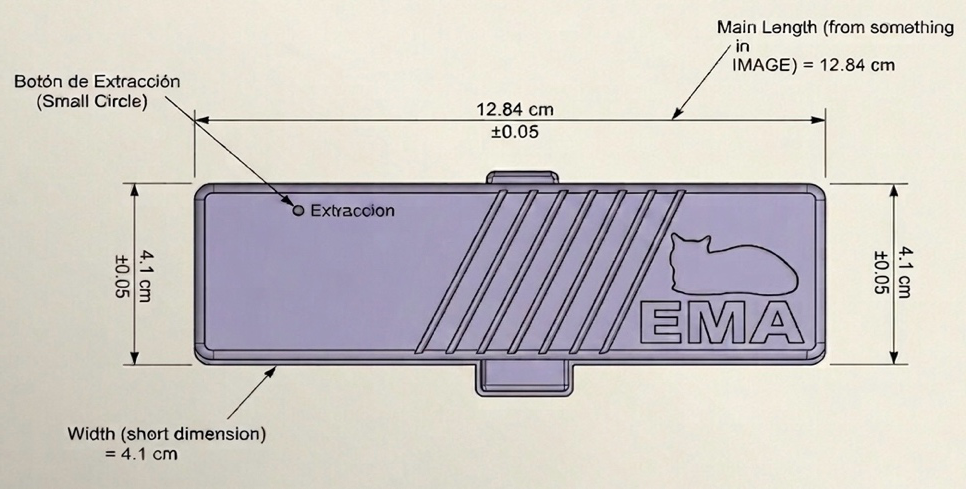
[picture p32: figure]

Ilustración 25: Botón de extracción carcasa superficial. Fuente: Propia SGC.

Acceso: Desde un dispositivo móvil, conéctese a la red inalámbrica "Masa_Prototipo" utilizando la clave de seguridad 12345678.

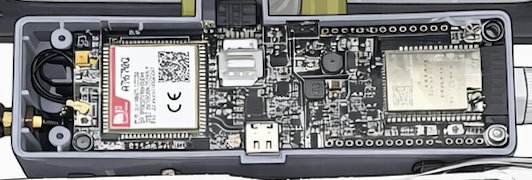
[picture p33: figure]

Botón de extracción

Ilustración 26: Botón de extracción. Fuente: Propia SGC.

Descarga: Acceda al navegador e ingrese la dirección IP 192.168.4.1. Allí podrá visualizar y descargar el historial completo de eventos en formato .txt.

Ilustración 17: Dirección IP. Fuente: Propia SGC.

Cierre: Al finalizar la gestión desde la interfaz web, seleccione la opción de salida en el navegador. Esto cancelará el modo de extracción y devolverá el equipo a su protocolo de monitoreo de ultra bajo consumo.

Ilustración 27: Detener extracción de datos. Fuente: Propia SGC.

## 4.8 Manipulación, Transporte y Almacenamiento

### Transporte:

El disco encoder debe fijarse con tornillos M3 a su base en ABS, deben asegurarse con espuma para evitar desalineaciones durante el traslado.

### Almacenamiento:

Retirar la batería si el equipo no estará en uso por más de 30 días para evitar descargas profundas y daños químicos.

## 4.9 Actividades de Calibración y Verificación Inicial

### Verificación Inicial:

Realizar una prueba de giro manual del disco encoder para confirmar que el ESP32 despierta y el módem envía la trama correctamente.

El sistema traduce las señales digitales (pulsos) capturadas por el sensor óptico H206 en unidades de medida física (centímetros) mediante un modelo matemático que integra las dimensiones del hardware y la validación experimental.

## A. Parámetros Geométricos del Diseño

El cálculo base parte de las dimensiones físicas de la polea donde se enrolla el hilo de tracción:

- Diámetro Base: 5.10 cm (51 mm).
- Circunferencia: Representa la distancia teórica que el hilo recorre en una vuelta completa del disco.

C=π*d=3.14159* 5.10 ≈16.02 cm

Resolución=16.02/(20 ranuras)=0.801 cm por pulso

Gracias al cálculo podemos determinar cuántos centímetros por pulso tenemos en cada una de las ranuras de la rueda de encoder óptico.

## B. Calibración Experimental (Factor de Ajuste Real)

Debido a variables mecánicas como el grosor del hilo y el rozamiento, se realizó una prueba de calibración de campo donde se determinó que el sistema registra 125 pulsos por cada 100 cm de desplazamiento lineal. De esta relación surge la constante de programación utilizada en el firmware:

Factor Real ((cm)/(pulso))=(100 cm)/(125 pulsos reales)=0.8000 cm por pulso

## C. Formulación Matemática de Medición

La distancia total desplazada () que el equipo reporta al servidor (vía MQTT) y almacena en la MicroSD se obtiene mediante la siguiente ecuación de control:

D= P( Pulsos reales)*0.8000 cm por pulso

Donde:

- D: Distancia final de desplazamiento en centímetros (cm).
- P: Número total de pulsos detectados por el sensor en el Pin 32.
- 0.8000: Constante de calibración que garantiza la precisión del sistema en el monitoreo de movimientos en masa.

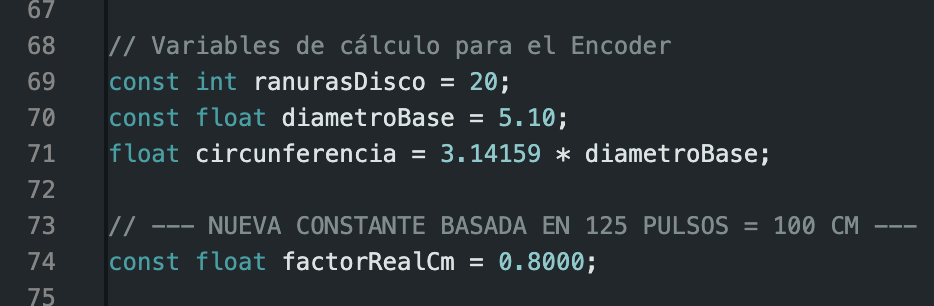
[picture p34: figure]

Ilustración 28: Calibración. Fuente: Propia SGC.

### Comprobación de Tiempo:

Validar que el estampado de tiempo coincida con la hora local actual antes del despliegue final.

## 4.10 Referencia a Documentos Complementarios

Datasheet y Pinout LilyGO T-A7670G: Documento técnico esencial que detalla la distribución de los pines del ESP32, la gestión de energía del módem y el esquema de carga de la batería.

- Referencia: Xinyuan-LilyGO T-A7670 Series Hardware Manual. * Enlace: GitHub Oficial LilyGO - Hardware T-A7670 (https://www.google.com/search?q=https://github.com/Xinyuan-LilyGO/LilyGO-T-A7670&authuser=2)

Manual de Comandos AT SIMCom A7670 Series: Guía técnica para entender cómo el microcontrolador se comunica con el módem para enviar las tramas CSV vía MQTT.

- Referencia: SIMCom A7670 Series_AT Command Manual. * Enlace: Documentación Técnica SIMCom (https://www.simcom.com/product/A7670X.html)

Documentación de Referencia Node-RED: Manual de usuario para la configuración de los flujos de recepción de datos y la gestión de la interfaz de visualización (Dashboard).

- Referencia: Node-RED Documentation - Getting Started. * Enlace: Node-RED Official Docs (https://nodered.org/docs/)

Especificaciones del Sensor Infrarrojo de Herradura (H206): Ficha técnica que define los niveles de voltaje y la lógica de salida digital necesaria para el conteo de pulsos del encoder.

- Referencia: Generic H206 / ITR9608 Optical Sensor Datasheet. * Enlace: Datasheet ITR9608 (Componente base del H206) (https://www.google.com/search?authuser=2)

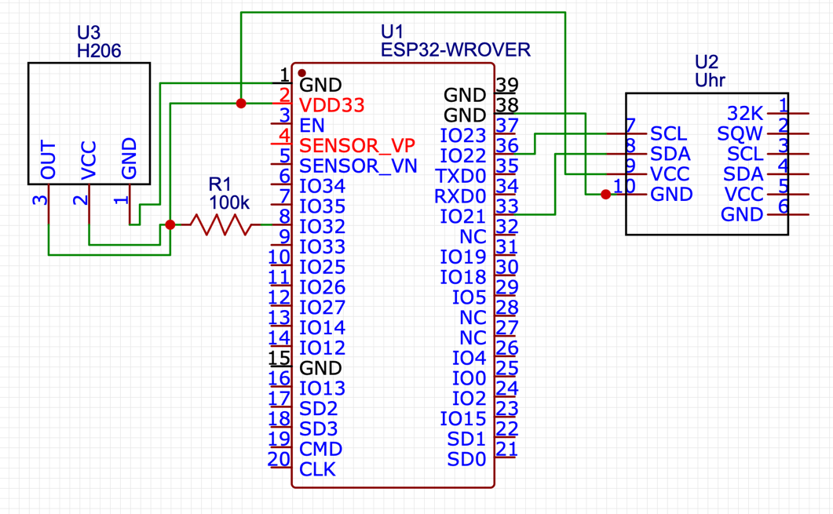
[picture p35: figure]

Ilustración 20: PinOut. Fuente: Propia SGC.

# 5. DOCUMENTOS Y REGISTROS ASOCIADOS

No aplica

# 6. CONTROL DE CAMBIOS

Versión | Fecha | Descripción de los Cambios
1
2
3
4

ELABORÓ | REVISÓ | APROBÓ
Nombre: Jhoiner Andretty Silva Montaño Cargo: Contratista | Nombre: Cargo: Nombre: Cargo: Nombre: Cargo: | Nombre: Cargo: Nombre: Cargo:

Nota 1: Utilice letra Verdana Tamaño 11 color negro Interlineado Mínimo 12 pto. Al finalizar el documento recuerde eliminar todas las indicaciones resaltadas en color gris, excepto la marca de agua “COPIA NO CONTROLADA”.

Página 5 de 5 Versión 01 2025-09-23 F-PSG-009

Página 1 de 5 Versión 01 2025-09-23 F-PSG-009

MANUAL DE OPERACIÓN CÓDIGO: xx-xxx--xx-xx Nombre del documento VERSIÓN: x CLASIFICACIÓN DE LA INFORMACIÓN x

MANUAL DE OPERACIÓN CÓDIGO: MO-GGC-IDG-001 Nombre del documento VERSIÓN: x CLASIFICACIÓN DE LA INFORMACIÓN x

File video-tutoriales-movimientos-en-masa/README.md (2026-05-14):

# 📥 Guía de extracción de datos (Modo Comunitario / Técnico)

Este documento describe el protocolo para la descarga de datos históricos directamente desde el nodo **EMA** sin necesidad de conexión a internet, utilizando el servidor web local integrado en el firmware.

## 🎥 Video demostrativo
*(En esta carpeta se encuentra el archivo `VIDEO-EXTRACCION.mp4` que ilustra los pasos descritos a continuación).*

## 🛠️ Procedimiento de extracción paso a paso

### 1. Activación del modo AP (punto de acceso)
Para despertar el Wi-Fi del nodo, localice el orificio de servicio en la parte frontal del chasis:
* Inserte una herramienta fina para presionar el botón de **BOOT (Pin 0)** durante 2 segundos.
* El nodo detendrá temporalmente la telemetría MQTT para levantar el servidor web local.

### 2. Conexión al nodo
Desde un smartphone o computadora, busque las redes Wi-Fi disponibles:
* **SSID:** `Masa_Prototipo`
* **Contraseña:** `12345678` (Configuración por defecto).

### 3. Acceso a la interfaz de usuario
Abra su navegador web (Chrome, Safari o Firefox) e ingrese la dirección IP estática:
* **IP:** `192.168.4.1`

### 4. Descarga de archivos
En el panel de control web encontrará las siguientes opciones:
* **Visualización:** Monitoreo del desplazamiento acumulado y voltaje de batería.
* **Descarga SD:** Permite bajar el archivo `DATA.CSV` almacenado en la MicroSD.
* **Descarga interna:** respaldo almacenado en la memoria LittleFS (Redundancia).

### 5. Finalización y reposo
**IMPORTANTE:** Una vez terminada la descarga, presione el botón **"Apagar Wi-Fi y Dormir"** en la interfaz web. Esto asegura que el nodo cierre el servidor y vuelva a su estado de bajo consumo para continuar con la vigilancia geológica.

## 📊 Formato de datos
Los archivos descargados están en formato `.CSV o .TXT` (valores separados por comas), compatibles con Excel o software de análisis de datos, con la siguiente estructura:
`fecha, hora, desplazamiento(m), batería(V), señal(dBm)`

---
**Desarrollado por:** Jhoiner Andretty Silva Montaño  
**Entidad:** Servicio Geológico Colombiano  
**Año:** 2026

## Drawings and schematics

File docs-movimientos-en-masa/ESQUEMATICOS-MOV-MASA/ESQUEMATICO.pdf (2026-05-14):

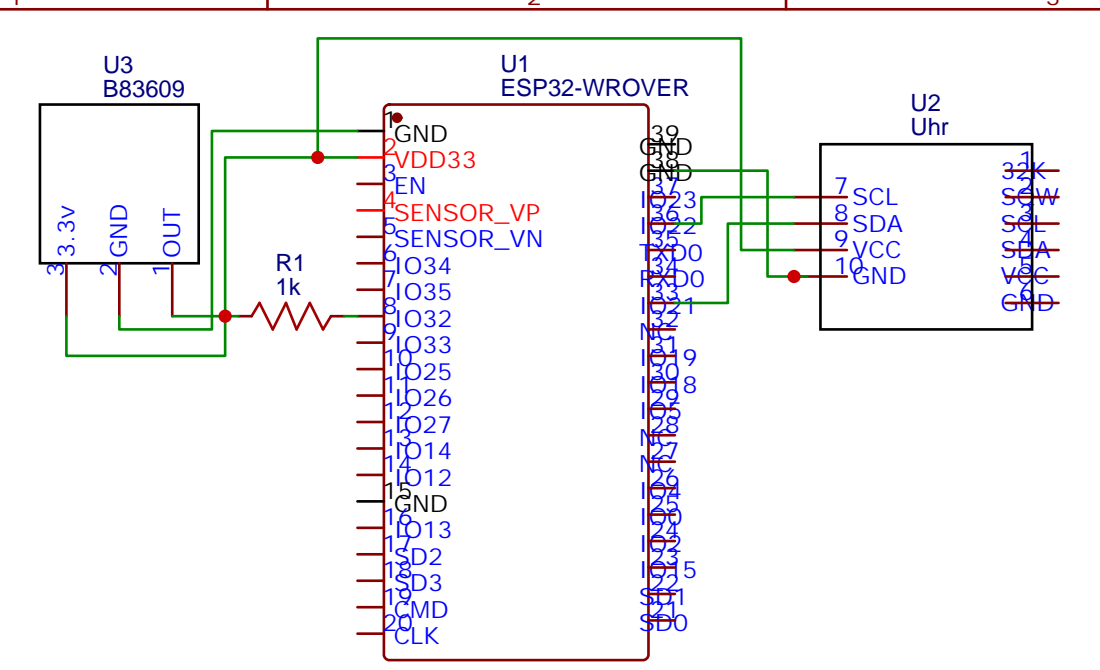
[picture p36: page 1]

Drawn By: Jhoiner Andretty Silva Monta o

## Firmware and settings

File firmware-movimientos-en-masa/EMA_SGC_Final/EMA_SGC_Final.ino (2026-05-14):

#include <Arduino.h>
#include <esp_task_wdt.h>  
#include "driver/gpio.h" 
#include "driver/rtc_io.h" 
#include "FS.h"
#include "SD.h"
#include "SPI.h"
#include "LittleFS.h"
#include <Wire.h>         
#include <RTClib.h>       

// --- LIBRERÍAS PARA EL PORTAL WI-FI ---
#include <WiFi.h>
#include <WebServer.h>

// --- CONFIGURACIÓN DE SEGURIDAD (Archivo externo) ---
#include "config_env.h"

// --- 1. CONFIGURACIÓN DEL MÓDEM A7670G ---
#define TINY_GSM_MODEM_SIM7600  
#define MODEM_TX             26 
#define MODEM_RX             27
#define PIN_MODEM_POWER      12 // Llave maestra de energía (SD y LDO del Módem)
#define PIN_MODEM_PWRKEY      4 // Botón interno (Para apagar/encender celular)

// --- 2. CONFIGURACIÓN DE SENSORES Y PINES ---
#define PIN_ENCODER          GPIO_NUM_32 
#define PIN_BOTON_WIFI       GPIO_NUM_0   // BOTÓN DE EXTRACCIÓN EN EL PIN 0 (BOOT)
#define BOTON_WIFI_MASK      (1ULL << 0)  // MÁSCARA PARA EL PIN 0
#define PIN_BATTERY          35 

// --- PINES I2C PARA EL RTC ---
#define I2C_SDA              21
#define I2C_SCL              22

// --- PINES SPI PERSONALIZADOS PARA LILYGO T-A7670 (MICRO SD) ---
#define PIN_SD_MISO           2
#define PIN_SD_MOSI          15
#define PIN_SD_SCLK          14
#define PIN_SD_CS            13 

#include <TinyGsmClient.h>
#include <PubSubClient.h>

// --- 3. CREDENCIALES DE RED Y MQTT (Desde config_env.h) ---
const char apn[]      = SECRET_APN; 
const char gprsUser[] = SECRET_GPRS_USER;
const char gprsPass[] = SECRET_GPRS_PASS;

const char* mqtt_server = SECRET_MQTT_SERVER;
const int   mqtt_port   = SECRET_MQTT_PORT;
const char* mqtt_user   = SECRET_MQTT_USER;
const char* mqtt_pass   = SECRET_MQTT_PASS;
const char* mqtt_topic  = SECRET_MQTT_TOPIC; 

// --- 4. CONFIGURACIÓN DE TIEMPOS Y WATCHDOG ---
#define uS_TO_S_FACTOR 1000000ULL 
#define TIEMPO_DORMIR_SEG 3600  // Tiempo de envío de datos      
#define WDT_TIMEOUT 120             

// --- 5. MEMORIA RTC (Sobrevive al Deep Sleep) ---
RTC_DATA_ATTR int contador_pulsos = 0;
RTC_DATA_ATTR int dia_anterior = -1;  
RTC_DATA_ATTR unsigned long registro_numero = 0;
RTC_DATA_ATTR bool modem_encendido = true; 
RTC_DATA_ATTR bool esperando_bloqueo = true; 

RTC_DS3231 rtc; 

// Variables de cálculo para el Encoder
const int ranurasDisco = 20;
const float diametroBase = 5.10; 
float circunferencia = 3.14159 * diametroBase;
const float factorRealCm = 0.8000; 

HardwareSerial SerialAT(1);
TinyGsm modem(SerialAT);
TinyGsmClient client(modem);
PubSubClient mqtt(client);

WebServer server(80);
bool modo_wifi_activo = false;
TaskHandle_t TareaSensorHandle = NULL;

// =========================================================================
//                  TAREA DEL NÚCLEO 1: LECTURA DEL SENSOR
// =========================================================================
void TareaLecturaSensor(void * pvParameters) {
    for(;;) {
        if (esperando_bloqueo == true && digitalRead(PIN_ENCODER) == 0) {
            esperando_bloqueo = false; 
        } 
        else if (esperando_bloqueo == false && digitalRead(PIN_ENCODER) == 1) {
            contador_pulsos++;
            esperando_bloqueo = true; 
            Serial.print("PULSO DETECTADO (N1): "); Serial.println(contador_pulsos);
        }
        vTaskDelay(1 / portTICK_PERIOD_MS); 
    }
}

// =========================================================================
//                  ZONA DEL SERVIDOR WEB (WI-FI)
// =========================================================================

void configurarServidorWeb() {
  server.on("/", HTTP_GET, []() {
    String uuid_esp32 = WiFi.softAPmacAddress();
    int bat = obtenerPorcentajeBateria();
    
    SPI.begin(PIN_SD_SCLK, PIN_SD_MISO, PIN_SD_MOSI, PIN_SD_CS);
    bool sd_ok = SD.begin(PIN_SD_CS, SPI);
    if(sd_ok) SD.end();

    float distanciaM = (contador_pulsos * factorRealCm) / 100.0;

    String html = "<!DOCTYPE html><html><head><meta charset='UTF-8'><meta name='viewport' content='width=device-width, initial-scale=1'><title>Monitoreo de Masa</title>";
    html += "<style>body{font-family:sans-serif; background:#eef2f3; padding:20px;} .panel{background:white; border-radius:10px; padding:20px; margin-bottom:20px; box-shadow:0 2px 5px rgba(0,0,0,0.1);} ";
    html += "h1{text-align:center; color:#2c3e50;} .uuid{text-align:center; color:#7f8c8d; font-family:monospace; margin-bottom:20px;} ";
    html += "a{display:block; background:#2196F3; color:white; padding:15px; text-align:center; text-decoration:none; border-radius:8px; margin:10px 0; font-weight:bold;} ";
    html += ".btn-exit{background:#e74c3c;}</style></head><body>";
    
    html += "<h1>Nodo Movimientos en Masa</h1>";
    html += "<p class='uuid'>S/N: " + uuid_esp32 + "</p>";

    html += "<div class='panel'><h2>Estado en Vivo</h2>";
    html += "<p style='background-color:#e8f4f8; padding:10px; border-radius:5px;'><strong>📊 Desplazamiento:</strong> " + String(distanciaM, 3) + " metros</p>";
    html += "<p style='font-size:12px; color:#7f8c8d;'>* Recarga la pagina para actualizar</p>";
    html += "<hr>";
    html += "<p><strong>Bateria:</strong> " + String(bat) + "%</p>";
    html += "<p><strong>SD Card:</strong> " + String(sd_ok ? "OK" : "ERROR") + "</p>";
    html += "</div>";

    html += "<div class='panel'><h2>Descargar Datos</h2>";
    html += "<a href='/descargar_sd'>1. Respaldo MicroSD (.csv)</a>";
    html += "<a href='/descargar_interno'>2. Respaldo Memoria Interna (.csv)</a>";
    html += "</div>";

    html += "<a href='/salir' class='btn-exit'>Apagar Wi-Fi y Dormir</a>";
    html += "</body></html>";
    server.send(200, "text/html", html);
  });

  server.on("/descargar_sd", HTTP_GET, []() {
    SPI.begin(PIN_SD_SCLK, PIN_SD_MISO, PIN_SD_MOSI, PIN_SD_CS);
    if (!SD.begin(PIN_SD_CS, SPI)) { server.send(500, "text/plain", "Error SD"); return; }
    File file = SD.open("/backup_masa.csv", FILE_READ);
    server.streamFile(file, "application/octet-stream");
    file.close(); SD.end();
  });

  server.on("/descargar_interno", HTTP_GET, []() {
    if (!LittleFS.begin(true)) { server.send(500, "text/plain", "Error FS"); return; }
    File file = LittleFS.open("/backup_interno.csv", FILE_READ);
    server.streamFile(file, "application/octet-stream");
    file.close(); LittleFS.end();
  });

  server.on("/salir", HTTP_GET, []() { server.send(200, "text/plain", "Cerrando..."); delay(1000); modo_wifi_activo = false; });
}

void iniciarPortalMantenimiento() {
  WiFi.disconnect(true); 
  WiFi.mode(WIFI_OFF); 
  delay(100);
  
  WiFi.persistent(false); 
  WiFi.mode(WIFI_AP);
  WiFi.softAP("Masa_Prototipo", SECRET_WIFI_AP_PASS);
  
  configurarServidorWeb();
  server.begin();
  modo_wifi_activo = true;
  
  Serial.println(">>> PORTAL WI-FI ACTIVO: Masa_Prototipo <<<");
  
  while (modo_wifi_activo) { 
    esp_task_wdt_reset(); 
    server.handleClient(); 
    delay(10); 
  }

  Serial.println("Sincronizando mediciones con MQTT antes de finalizar...");
  transmitirDatos(); 

  WiFi.softAPdisconnect(true); 
  WiFi.mode(WIFI_OFF);
  Serial.println("Portal cerrado. Volviendo a modo ahorro.");
}

// =========================================================================
//                  ZONA DE FUNCIONES MÓDEM, BATERÍA Y SD
// =========================================================================

int obtenerPorcentajeBateria() {
  delay(100); 
  pinMode(PIN_BATTERY, INPUT);
  long suma_adc = 0;
  for(int i = 0; i < 10; i++) {
    suma_adc += analogRead(PIN_BATTERY);
    delay(10);
  }
  float adc_promedio = suma_adc / 10.0;
  float voltaje_bateria = (adc_promedio / 4095.0) * 3.3 * 2.0 * 1.097;
  int porcentaje = map(voltaje_bateria * 100, 320, 420, 0, 100);
  if (porcentaje > 100) porcentaje = 100;
  if (porcentaje < 0) porcentaje = 0;
  return porcentaje;
}

void sincronizarRTCConRed() {
  int año, mes, dia, hora, min, seg;
  float zona;
  if (modem.getNetworkTime(&año, &mes, &dia, &hora, &min, &seg, &zona)) {
    rtc.adjust(DateTime(año, mes, dia, hora, min, seg));
    Serial.println("🕒 RTC Sincronizado correctamente.");
  }
}

void obtenerFechaHora(char* fecha, char* hora) {
  DateTime now = rtc.now();
  sprintf(fecha, "%02d/%02d/%02d", now.day(), now.month(), now.year() % 100);
  sprintf(hora, "%02d:%02d:%02d", now.hour(), now.minute(), now.second());
}

void transmitirDatos() {
  Serial.println("\n--- INICIANDO PROTOCOLO DE TRANSMISIÓN ---");
  int pct_bateria = obtenerPorcentajeBateria();
  Serial.print("Nivel de Batería: "); Serial.print(pct_bateria); Serial.println("%");
  
  if (pct_bateria < 15 && modem_encendido) {
    Serial.println("⚠️ ALERTA: Batería crítica (<15%). Apagando módem celular.");
    pinMode(PIN_MODEM_PWRKEY, OUTPUT);
    digitalWrite(PIN_MODEM_PWRKEY, HIGH);
    delay(2500); 
    digitalWrite(PIN_MODEM_PWRKEY, LOW);
    modem_encendido = false;
  } 
  else if (pct_bateria >= 20 && !modem_encendido) {
    Serial.println("☀️ RECUPERACIÓN: Batería estable (>=20%). Encendiendo módem.");
    pinMode(PIN_MODEM_PWRKEY, OUTPUT);
    digitalWrite(PIN_MODEM_PWRKEY, HIGH);
    delay(1500); 
    digitalWrite(PIN_MODEM_PWRKEY, LOW);
    delay(5000);
    esp_task_wdt_reset(); 
    delay(5000);
    modem_encendido = true;
    SerialAT.begin(115200, SERIAL_8N1, MODEM_RX, MODEM_TX);
    modem.init();
    modem.sendAT("+CTZU=1");
    modem.waitResponse(5000L);
  }

  char bat_str[4];
  sprintf(bat_str, "%03d", pct_bateria);
  char fecha[12], hora[12];
  
  if (modem_encendido) {
    SerialAT.begin(115200, SERIAL_8N1, MODEM_RX, MODEM_TX);
    delay(500);
    for (int i = 0; i < 3; i++) { SerialAT.println("AT"); delay(150); }
    if (modem.waitForNetwork(60000L)) {
      sincronizarRTCConRed(); 
    }
    esp_task_wdt_reset(); 
  }

  obtenerFechaHora(fecha, hora);
  float distanciaM = (contador_pulsos * factorRealCm) / 100.0;
  char payload_char[150];
  sprintf(payload_char, "{\"f\":\"%s\",\"h\":\"%s\",\"d\":%.3f,\"b\":\"%s\"}", fecha, hora, distanciaM, bat_str);
  String payload = String(payload_char);

  // 1. Guardar en SD
  SPI.begin(PIN_SD_SCLK, PIN_SD_MISO, PIN_SD_MOSI, PIN_SD_CS);
  if (SD.begin(PIN_SD_CS, SPI)) {
    File f = SD.open("/backup_masa.csv", FILE_APPEND);
    if(f) { 
      f.println("Registro: " + String(registro_numero) + " | " + payload); 
      f.close(); 
      Serial.println("[OK] Guardado en SD.");
    }
    SD.end();
  } else {
    Serial.println("[ERROR] No se pudo escribir en la SD.");
  }

  // 2. Guardar en LittleFS (Memoria Interna)
  if (LittleFS.begin(true)) {
    File f = LittleFS.open("/backup_interno.csv", FILE_APPEND);
    if(f) { 
      f.println("Registro: " + String(registro_numero) + " | " + payload); 
      f.close(); 
      Serial.println("[OK] Guardado en Memoria Interna.");
    }
    LittleFS.end();
  }

  // 3. Enviar por MQTT
  if (modem_encendido) {
    if (!modem.isGprsConnected()) {
      Serial.println("Conectando GPRS...");
      if (modem.gprsConnect(apn, gprsUser, gprsPass)) {
        mqtt.setServer(mqtt_server, mqtt_port);
        if (mqtt.connect("NodoMasa", mqtt_user, mqtt_pass)) {
          mqtt.publish(mqtt_topic, payload.c_str());
          Serial.println("[OK] MQTT Publicado.");
          delay(1000);
          mqtt.disconnect();
        }
      }
    }
  }
  
  registro_numero++;
}

// =========================================================================
//                          BUCLE PRINCIPAL (SETUP)
// =========================================================================

void setup() {
  esp_task_wdt_config_t wdt_config;
  wdt_config.timeout_ms = WDT_TIMEOUT * 1000; 
  wdt_config.idle_core_mask = 3; 
  wdt_config.trigger_panic = true; 
  esp_task_wdt_reconfigure(&wdt_config); 
  esp_task_wdt_add(NULL); 

  pinMode(PIN_MODEM_PWRKEY, OUTPUT);
  digitalWrite(PIN_MODEM_PWRKEY, LOW); 
  gpio_hold_dis((gpio_num_t)PIN_MODEM_PWRKEY); 

  pinMode(MODEM_TX, OUTPUT);
  digitalWrite(MODEM_TX, HIGH); 
  gpio_hold_dis((gpio_num_t)MODEM_TX); 

  Serial.begin(115200);
  delay(100);
  Wire.begin(I2C_SDA, I2C_SCL);
  if (!rtc.begin()) Serial.println("❌ RTC No Encontrado");

  xTaskCreatePinnedToCore(TareaLecturaSensor, "TaskSensor", 4096, NULL, 1, &TareaSensorHandle, 1);
  
  pinMode(0, INPUT_PULLUP);
  if (digitalRead(0) == LOW || esp_sleep_get_wakeup_cause() == ESP_SLEEP_WAKEUP_EXT1) {
      Serial.println("!!! ENTRANDO A PORTAL POR PRESIÓN DE BOTÓN !!!");
      iniciarPortalMantenimiento();
  }

  esp_sleep_wakeup_cause_t causa_despertar = esp_sleep_get_wakeup_cause();

  switch (causa_despertar) {
    
    case ESP_SLEEP_WAKEUP_EXT1:
      break;

      case ESP_SLEEP_WAKEUP_EXT0:
      Serial.println(">>> MOVIMIENTO DETECTADO <<<");
      {
        unsigned long t_ultimo_pulso = millis();
        unsigned long t_inicio_jalon = millis(); 
        int conteo_anterior = contador_pulsos;

        Serial.println("Esperando más movimientos antes de transmitir...");

        while ((millis() - t_ultimo_pulso < 5000) && (millis() - t_inicio_jalon < 30000)) {
            esp_task_wdt_reset(); 
            if (contador_pulsos > conteo_anterior) {
                conteo_anterior = contador_pulsos;
                t_ultimo_pulso = millis(); 
                Serial.print("PULSO ACUMULADO: "); Serial.println(contador_pulsos);
            }
            delay(10); 
        }

        if (millis() - t_inicio_jalon >= 30000) {
            Serial.println("Límite de 30s alcanzado. Transmitiendo medida parcial...");
        } else {
            Serial.println("Calma detectada por 5 segundos. Procediendo a transmitir...");
        }
      }
      transmitirDatos(); 
      break;

    case ESP_SLEEP_WAKEUP_TIMER:
      Serial.println("Ciclo completado. Procesando datos...");
      transmitirDatos();
      break;

    default:
      Serial.println("\n--- ARRANQUE EN FRÍO ---");
      contador_pulsos = 0; dia_anterior = -1; registro_numero = 0; modem_encendido = true; 
      esperando_bloqueo = true; 
      Serial.println("Iniciando llave maestra (Pin 12 -> HIGH)...");
      gpio_hold_dis((gpio_num_t)PIN_MODEM_POWER); 
      pinMode(PIN_MODEM_POWER, OUTPUT);
      digitalWrite(PIN_MODEM_POWER, HIGH); 
      gpio_hold_en((gpio_num_t)PIN_MODEM_POWER);
      gpio_deep_sleep_hold_en(); 
      delay(10000);
      esp_task_wdt_reset(); 
      SerialAT.begin(115200, SERIAL_8N1, MODEM_RX, MODEM_TX);
      modem.init();
      modem.sendAT("+CTZU=1");
      modem.waitResponse(5000L);
      transmitirDatos();
      break;
  }
  
  if (TareaSensorHandle != NULL) vTaskDelete(TareaSensorHandle);

  pinMode(32, INPUT_PULLUP);
  rtc_gpio_pullup_en(PIN_ENCODER);
  rtc_gpio_pulldown_dis(PIN_ENCODER);

  if (esperando_bloqueo == true) {
      esp_sleep_enable_ext0_wakeup(PIN_ENCODER, 0);
  } else {
      esp_sleep_enable_ext0_wakeup(PIN_ENCODER, 1);
  }

  rtc_gpio_init(GPIO_NUM_0);
  rtc_gpio_set_direction(GPIO_NUM_0, RTC_GPIO_MODE_INPUT_ONLY);
  rtc_gpio_pullup_en(GPIO_NUM_0);
  rtc_gpio_pulldown_dis(GPIO_NUM_0);
  esp_sleep_enable_ext1_wakeup(BOTON_WIFI_MASK, ESP_EXT1_WAKEUP_ALL_LOW);
  esp_sleep_enable_timer_wakeup(TIEMPO_DORMIR_SEG * uS_TO_S_FACTOR);

  Serial.println("Entrando en Deep Sleep..."); Serial.flush(); 
  SerialAT.end();
  gpio_hold_en((gpio_num_t)PIN_MODEM_PWRKEY); 
  pinMode(MODEM_TX, OUTPUT);
  digitalWrite(MODEM_TX, HIGH); 
  gpio_hold_en((gpio_num_t)MODEM_TX); 
  esp_deep_sleep_start();
}

void loop() {}

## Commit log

2026-05-14 carpetas principales
    [BASESENSOROPTICOINICIAL.stl, CARRETE.stl, CARRETEDIVIDIDO#1.stl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]
2026-05-14 ACTUALIZACION 3D
    [BASESENSOROPTICOINICIAL.stl, CARRETE-CALIBRADOR.stl, CARRETE-NYLON.stl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]
